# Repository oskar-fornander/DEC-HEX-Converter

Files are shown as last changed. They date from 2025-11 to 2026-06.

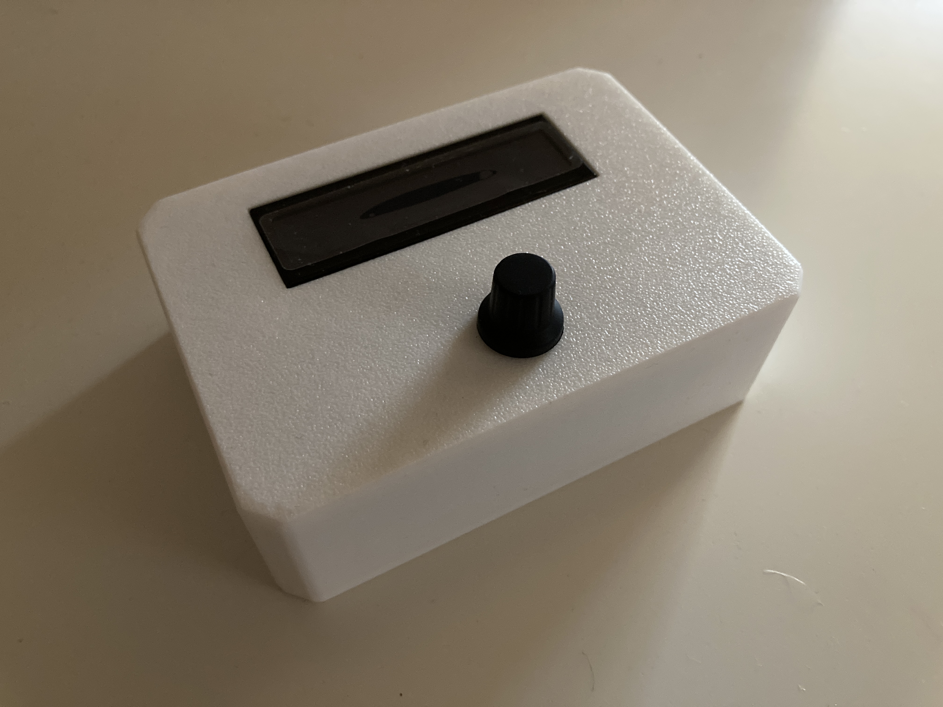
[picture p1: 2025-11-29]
model_b/images/DEC-HEX-Converter_B_01.jpg

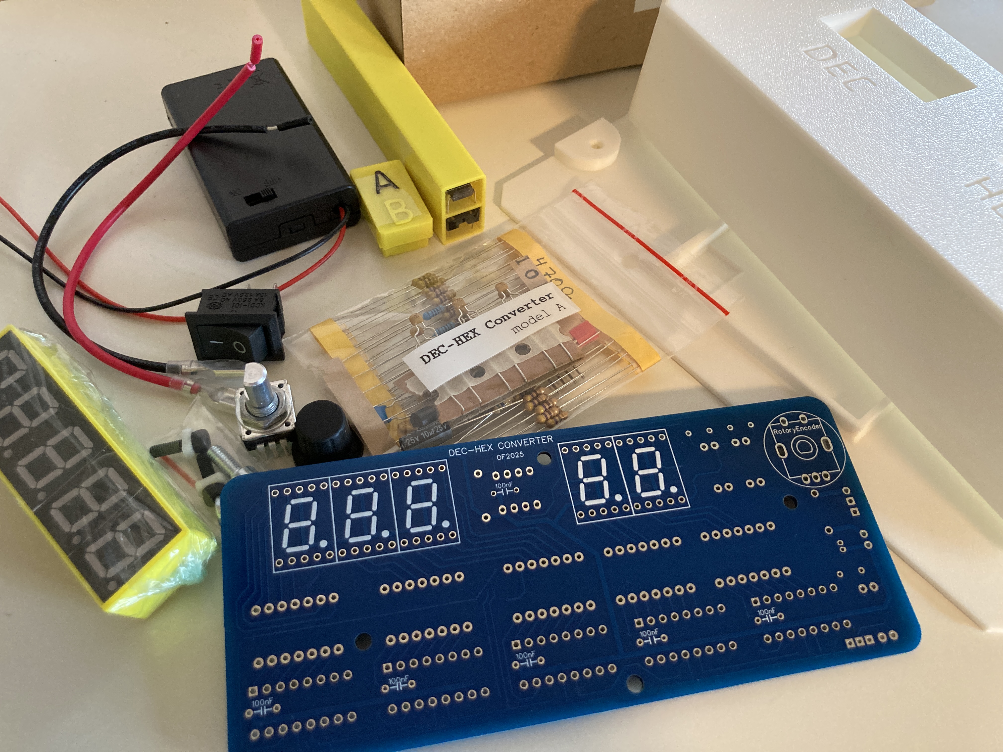
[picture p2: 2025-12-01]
model_a/images/DEC-HEX-Converter_A_05.JPG

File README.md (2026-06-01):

# DEC–HEX Converter: DIY Electronics Kit (Models A & B)

This repository contains the firmware, hardware design, and comprehensive documentation for the **DEC–HEX Converter**, a fun and functional DIY calculator kit. It is designed to help hobbyists practice their soldering skills while creating a useful, physical tool for converting between number systems.

**Quick Navigation:**
* [**Documentation in Swedish**](sv/README.md)
* **Ready to Buy?** See the [**Ordering Guide**](ordering.md)

## Key Features (Common to Both Models)

The DEC–HEX Converter is built around a simple, tactile interface:

* **Fast Conversion:** Quickly convert between Decimal and Hexadecimal number bases (and Binary depending on the model).
* **Rotary Encoder:** Use the responsive and precise rotary encoder to increment/decrement values. It provides satisfying tactile feedback with distinct steps for each change.
* **Intuitive Control:** **Rotate** to count up/down, and **Press** to reset the counter to zero.
* **The Brain:** Both units use the reliable **ATtiny85/45 microcontroller** for processing.
* **Enclosure:** The electronics are housed in a robust **3D-printed enclosure**.
* **The Kit:** Delivered as a complete kit with a **custom-designed PCB**, all necessary components, and a **pre-programmed microcontroller**—ideal for excellent **soldering practice**.
* **Customization:** The microcontroller is pre-programmed, but it can be **re-programmed**. The source code is available within this repository.

## Two Models

The DEC–HEX Converter comes in two variants, catering to different preferences for display type and soldering complexity:

### Model A: The Classic Display
* Displays values using bright, classic **seven-segment displays**.
* Converts between **Decimal** and **Hexadecimal**.
* Features a **dedicated power switch** and a power-saving sleep mode.
* *Involves more soldering.*

### Model B: The LCD Multi-Base Display
* Displays values on an **LCD (Liquid Crystal Display)**.
* Converts between **Decimal**, **Hexadecimal**, and **Binary**.
* **No power switch**; utilizes an ultra-low-power sleep mode and wakes up instantly when the knob is turned or pressed.
* *Involves less soldering.*

## Repository Contents

This repository is organized into specific directories for each model. All project files, documentation, and source code are provided below.

* **General Files:** Find pricing, licenses, and the Swedish documentation entry point.
* **Model-Specific:** Documentation, hardware files, and firmware are located within the dedicated `/model_a/` and `/model_b/` directories.

---

### Model A Files (`/model_a/`)

The following files are unique to the **seven-segment display** model:

| Document/File | Content Description | Path (Click to View) |
| :--- | :--- | :--- |
| **Firmware (.ino)** | The Arduino source code for the microcontroller. | [model\_a.ino](model_a/model_a.ino) |
| **Assembly Guide** | Step-by-step instructions for soldering and assembly. | [a\_assembly.md](model_a/docs/a_assembly.md) |
| **Specification** | Detailed feature list and technical specifications for Model A. | [a\_spec.md](model_a/docs/a_spec.md) |
| **Parts List** | Full Bill of Materials (BOM) listing all included components. | [a\_parts\_list.md](model_a/docs/a_parts_list.md) |
| **Schematics (PDF)** | Detailed hardware circuit diagram. | [a\_schematic.pdf](model_a/docs/a_schematic.pdf) |
| **Images** | Photos of the parts and the assembled unit. | [images/](model_a/images/) |
| **3D files** | Files for 3D-printing the enclosure. | [3d_model/](model_a/3d_model/) |

### Model B Files (`/model_b/`)

The following files are unique to the **LCD multi-base display** model:

| Document/File | Content Description | Path (Click to View) |
| :--- | :--- | :--- |
| **Firmware (.ino)** | The Arduino source code for the microcontroller. | [model\_b.ino](model_b/model_b.ino) |
| **Assembly Guide** | Step-by-step instructions for soldering and assembly. | [b\_assembly.md](model_b/docs/b_assembly.md) |
| **Specification** | Detailed feature list and technical specifications for Model B. | [b\_spec.md](model_b/docs/b_spec.md) |
| **Parts List** | Full Bill of Materials (BOM) listing all included components. | [b\_parts\_list.md](model_b/docs/b_parts_list.md) |
| **Schematics (PDF)** | Detailed hardware circuit diagram. | [b\_schematic.pdf](model_b/docs/b\_schematic.pdf) |
| **Images** | Photos of the parts and the assembled unit. | [images/](model_b/images/) |
| **3D files** | Files for 3D-printing the enclosure. | [3d_model/](model_b/3d_model/) |

### General Project Files

| File | Content Description | Path (Click to View) |
| :--- | :--- | :--- |
| **Order Guide** | Information on pricing and how to order your kit. | [ordering.md](ordering.md) |
| **Swedish Docs** | Entry point for all project documentation in Swedish. | [sv/](sv/README.md) |
| **License** | Software and hardware license information. | [LICENSE.md](LICENSE.md) |
---

**Interested in purchasing a kit?** Read more in the [**Ordering Guide**](ordering.md)!

---

> **A Note on Guarantees:** This is a hobby project. While I strive for high quality, I offer no formal guarantee. Please contact me directly if you encounter any issues with the unit or assembly process.

> **Sponsorship:** PCB prototypes for DEC-HEX-BIN Converter Model B were kindly sponsored by PCBWay.

/Oskar Fornander

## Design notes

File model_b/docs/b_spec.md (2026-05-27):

# DEC–HEX Converter, Model B

Electronics Kit

Looking for a sleek, physical device to quickly convert between decimal and hexadecimal values? This is the kit for you! You get the satisfaction of soldering and assembling it yourself, turning it into a rewarding and functional project.

* **Fast conversion** between decimal, hexadecimal, and binary numbers—in all directions.
* The **rotary encoder** provides responsive and precise tactile feedback, featuring distinct steps for each value increment/decrement.
* **Rotate** to count up/down, and **press** to reset the counter to zero.
* Values are displayed simultaneously in decimal, hexadecimal, and binary form using an **LCD (Liquid Crystal Display)**.
* **No power switch**; the unit automatically enters an **ultra-low-power sleep mode** after a period of inactivity. Wake the unit up by rotating the knob or pressing to reset.
* Powered by **4 AAA batteries**. Provides over **25 hours of active use**.
* The brain is an **ATtiny85/45 microcontroller**.
* Comes with a **3D-printed enclosure** (116mm x 82mm x 38mm).
* Delivered as a complete kit with carefully selected, high-quality components, a **pre-programmed microcontroller**, and a custom-designed **PCB**—making for simple assembly and excellent **soldering practice**. PCB prototypes for the current revision were kindly sponsored by PCBWay. Current kit use a slightly updated PCB revision with minor improvements compared to the version shown in some of the photos.
* The microcontroller (ATtiny85/45) is pre-programmed but can be **re-programmed**. The source code is available on GitHub.

*Read more in [**ordering.md**](../../ordering.md) for pricing and how to order your own kit.*

(Also check out Model A, which uses seven-segment displays instead of an LCD and involves slightly more soldering.)

/Oskar Fornander, 2025

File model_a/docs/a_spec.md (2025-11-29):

# DEC–HEX Converter, Model A

Electronics Kit

Looking for a sleek, physical device to quickly convert between decimal and hexadecimal values? This is the kit for you! You get the satisfaction of soldering and assembling it yourself, turning it into a rewarding and functional project.

* **Fast conversion** between decimal and hexadecimal numbers—in both directions.
* The **rotary encoder** provides responsive and precise tactile feedback, featuring distinct steps for each value increment/decrement.
* **Rotate** to count up/down, and **press** to reset the counter to zero.
* Values are displayed simultaneously in decimal and hexadecimal form using **seven-segment displays** (the color of the displays may vary from the images).
* Dedicated **power switch** for on/off control.
* Powered by **3 AAA batteries**. Provides over **10 hours of active use**.
* **Automatic sleep mode** after a few minutes of inactivity to save battery life. The display will blink intermittently to remind you to power the unit off.
* The brain is an **ATtiny85/45 microcontroller**, and shift registers are used to drive the displays.
* Comes with a **3D-printed enclosure** (172mm x 75mm x 38mm).
* Delivered as a complete kit with carefully selected, high-quality components, a **pre-programmed microcontroller**, and a custom-designed **PCB**—making for simple assembly and excellent **soldering practice**.
* The microcontroller (ATtiny85/45) is pre-programmed but can be **re-programmed**. The source code is available on GitHub.

*Read more in [**ordering.md**](../../ordering.md) for pricing and how to order your own kit.*

(Also check out Model B, which uses an LCD instead of seven-segment displays and shows binary values as well, but requires slightly less soldering.)

/Oskar Fornander, 2025

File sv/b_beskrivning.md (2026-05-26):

# DEC–HEX Converter, model B

Byggsats elektronik

Vill du ha ett smidigt sätt att konvertera mellan decimala och hexadecimala värden, och dessutom i form av en fysisk enhet, så ska du skaffa denna! Dessutom får du den som en byggsats med glädjen att löda ihop och montera den själv. 

- Snabb konvertering (åt alla håll) mellan decimala, hexadecimala och binära tal.
- Vredet ger taktil feedback och är responsiv och exakt, med fasta steg för varje värde. 
- Vrid för att räkna uppåt/nedåt och tryck för att nollställa räkneverket.
- Värden visas samtidigt i decimal, hexadecimal och binär form på en lcd.
- Ingen strömbrytare; enheten går själv i viloläge med mycket låg strömförbrukning efter en stunds inaktivitet. Väck enheten genom att virda på ratten eller trycka för att nollställa.
- Drivs av 4 AAA-batterier. Aktiv tid mer än 25 timmar.
- Hjärnan är en ATtiny85/45.
- 3D-printad inbyggnadslåda (116mm x 82mm x 38mm).
- Kommer som en byggsats med noggrant utvalda delar, förprogrammerad mikrokontroller och specialdesignad pcb – enkel montering och en god övning för att löda. PCB-prototyper för denna modell har sponsrats av PCBWay.
- Mikrokontrollern (ATtiny85/45) är förprogrammerad men kan också programmeras om.
- Levereras med alla komponenter välsorterade och packeterade i en kartong.

Kostnad: **599kr** Kan även köpas färdigmonterad (+500kr).

Frakt som spårbart paket med Postnord: 59kr

(Kolla även in modell A som istället för en LCD har sjusegmentdisplayer och erbjuder lite mer lödning.)

/Oskar Fornander, 2025

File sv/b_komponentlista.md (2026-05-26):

# Innehåll

Detta är innehållet i byggsatsen för **DEC-HEX Converter, model B**.

- [ ] 3D-printat hölje (1st)
- [ ] Specialdesignad PCB (1st) - PCB sponsrad av PCBWay
- [ ] Skruvar M3 (6st)
- [ ] Skruvar M4 (2st)
- [ ] 3D-printad distansbricka M3 2mm (2st)
- [ ] 3D-printad distansbricka M3 5mm (4st)
- [ ] Batterihållare (4 x AAA) (1st)
- [ ] DIL-hållare (DIP-8) (1st)
- [ ] ATtiny85/45, förprogrammerad (model B) (1st)
- [ ] LCD med I2C-kommunikation (1st)
- [ ] Anslutning för LCD, 4 stift (1st)
- [ ] Rotationsenkoder (1st)
- [ ] Ratt till rotationsenkoder (1st)
- [ ] Stiftlist (4 + 3 stift)
- [ ] NPN-transistor (PN2222A/2N2222A) (1st)
- [ ] LDO regulator MCP1702 (1st)
- [ ] Kondensator (elektrolyt) 47uF (1st)
- [ ] Kondensator (keramisk) 1uF (105 blå) (2st)
- [ ] Kondensator (keramisk) 100nF (1st)
- [ ] Kondensator (keramisk) 10nF (103 beige) (2st)
- [ ] Motstånd 1kΩ (1st) (brown-black-red)
- [ ] Motstånd 10kΩ (3st) (brown-black-orange)
- [ ] Motstånd 100kΩ (1st) (brown-black-yellow)

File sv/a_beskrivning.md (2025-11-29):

# DEC–HEX Converter, model A
Byggsats elektronik

Vill du ha ett smidigt sätt att konvertera mellan decimala och hexadecimala värden, och dessutom i form av en fysisk enhet, så ska du skaffa denna! Dessutom får du den som en byggsats med glädjen att löda ihop och montera den själv. 

- **Snabb konvertering** mellan decimala och hexadecimala tal – åt båda håll.
- **Rotationsenkodern** ger taktil feedback och är responsiv och exakt, med fasta steg för varje värde. 
- **Vrid** för att räkna uppåt/nedåt och **tryck** för att nollställa räkneverket.
- Värden visas samtidigt i decimal och hexadecimal form med **sjusegmentdisplayer** (färgen på displayerna kan vara en annan än på bilderna).
- **Strömbrytare** för att starta och stänga av.
- Drivs av **3 AAA-batterier**. Aktiv tid **mer än 10 timmar**.
- **Automatiskt viloläge** efter ett par minuters inaktivitet för att spara på batterierna: displayen blinkar i intervaller för att påminna dig om att stänga av den.
- Hjärnan är **mikrokontrollern ATtiny85/45** och skiftregister används för att skicka data till displayerna.
- Monteras i en **3D-printad inbyggnadslåda** (172mm x 75mm x 38mm).
- Kommer som en byggsats med noggrant utvalda delar, **förprogrammerad mikrokontroller** och **specialdesignad pcb** – enkel montering och en god övning för att löda.
- Mikrokontrollern (ATtiny85/45) är förprogrammerad men kan också **programmeras om**. Koden finns tillgänglig på GitHub.
- Levereras med alla komponenter välsorterade och packeterade i en kartong.

Kostnad: **599kr** Kan även köpas färdigmonterad (+500kr).

Frakt som spårbart paket med Postnord: 59kr

(Kolla även in modell B som istället för sjusegmentdisplayer har en LCD och även visar binära tal, men med lite mindre lödning.) 

/Oskar Fornander, 2025

(Detta är ett hobbyprojekt och jag lämnar ingen garanti, men ta kontakt om du får problem med enheten.)

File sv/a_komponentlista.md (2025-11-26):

# Innehåll

Detta är innehållet i byggsatsen för **DEC-HEX Converter, model A**.

- [ ] 3D-printat hölje (1st)
- [ ] Specialdesignad PCB (1st)
- [ ] Skruvar M3 (2st)
- [ ] Skruvar M4 (2st)
- [ ] 3D-printad distansbricka M3 2mm (2st)
- [ ] Batterihållare (3 x AAA) (1st)
- [ ] Strömbrytare med sladdar (1st)
- [ ] DIL-hållare DIP-16 (5st)
- [ ] Skiftregister (74HC595) (5st)
- [ ] DIL-hållare DIP-8 (1st)
- [ ] ATtiny85/45, förprogrammerad (model A) (1st)
- [ ] Sjusegmentdisplay (CA) (5st)
- [ ] Rotationsenkoder (1st)
- [ ] Ratt till rotationsenkoder (1st)
- [ ] Stiftlist (4 stift) (1st)
- [ ] Transistor (BC547B) (1st)
- [ ] Kondensator (elektrolyt) 10-47uF (1st)
- [ ] Kondensator (keramisk) 10uF (1st)
- [ ] Kondensator (keramisk) 100nF (6st)
- [ ] Kondensator (keramisk) 10nF (2st)
- [ ] Motstånd 470Ω (35st) (gul-lila-brun)
- [ ] Motstånd 10kΩ (6st) (brun-svart-orange)
- [ ] Motstånd 560kΩ (1st) (grön-blå-gul)
- [ ] Diod (1N5819) (1st)

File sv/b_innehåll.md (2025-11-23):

# Innehåll

Detta är innehållet i byggsatsen för **DEC-HEX Converter, model B**.

- [ ] 3D-printat hölje (1st)
- [ ] Specialdesignad PCB (1st)
- [ ] Skruvar M3 (6st)
- [ ] Skruvar M4 (2st)
- [ ] Bricka M3 2mm (2st)
- [ ] Bricka M3 5mm (4st)
- [ ] Batterihållare (4 x AAA) (1st)
- [ ] DIL-hållare (DIP-8) (1st)
- [ ] ATtiny85/45, förprogrammerad (model B) (1st)
- [ ] LCD med I2C-kommunikation (1st)
- [ ] Rotationsenkoder (1st)
- [ ] Ratt till rotationsenkoder (1st)
- [ ] Stiftlist (4 + 3 stift)
- [ ] NPN-transistor (PN2222A/2N2222A) (1st)
- [ ] LDO regulator MCP1702 (1st)
- [ ] Kondensator (elektrolyt) 47uF (1st)
- [ ] Kondensator (keramisk) 1uF (2st)
- [ ] Kondensator (keramisk) 100nF (1st)
- [ ] Kondensator (keramisk) 10nF (2st)
- [ ] Motstånd 1kΩ (1st) (brown-black-red)
- [ ] Motstånd 10kΩ (5st) (brown-black-orange)
- [ ] Motstånd 100kΩ (1st) (brown-black-yellow)

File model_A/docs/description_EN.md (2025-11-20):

# DEC–HEX Converter, Model A
Electronics Kit

Looking for a sleek, physical device to quickly convert between decimal and hexadecimal values? This is the kit for you! You get the satisfaction of soldering and assembling it yourself, turning it into a rewarding and functional project.

* **Fast conversion** between decimal and hexadecimal numbers—in both directions.
* The **rotary encoder** provides responsive and precise tactile feedback, featuring distinct steps for each value increment/decrement.
* **Rotate** to count up/down, and **press** to reset the counter to zero.
* Values are displayed simultaneously in decimal and hexadecimal form using **seven-segment displays** (the color of the displays may vary from the images).
* Dedicated power switch for **on/off** control.
* Powered by **3 AAA batteries**. Provides over **10 hours of active use**.
* **Automatic sleep mode** after a few minutes of inactivity to save battery life. The display will blink intermittently to remind you to power the unit off.
* The brain is an **ATtiny85/45 microcontroller**, and shift registers are used to drive the displays.
* Comes with a **3D-printed enclosure**.
* Delivered as a complete kit with carefully selected, high-quality components, a **pre-programmed microcontroller**, and a custom-designed **PCB**—making for simple assembly and excellent **soldering practice**.
* The microcontroller (ATtiny85/45) is pre-programmed but can be **re-programmed**. The source code is available on GitHub.
* All components are well-sorted and packaged in a box.

**Cost: 599 SEK** (Can also be purchased pre-assembled for +500 SEK).

Shipping as a trackable package with Postnord: 59 SEK

(Also check out Model B, which uses an LCD instead of seven-segment displays and shows binary values as well, but requires slightly less soldering.)

/Oskar Fornander, 2025

(This is a hobby project; I offer no guarantee, but please contact me if you encounter any problems with the unit.)

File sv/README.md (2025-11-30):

# DEC–HEX Converter: Elektronikbyggsats (Modell A & B)

Denna *repository* innehåller *firmware*, *hardware-design* och komplett dokumentation för **DEC–HEX Converter**, ett roligt och funktionellt byggsats-projekt. Den är utformad för att ge hobbyister chansen att öva sina lödkunskaper samtidigt som de skapar ett användbart, fysiskt verktyg för omvandling mellan talsystem.

**Snabblänkar:**
* [**Documentation in English**](../README.md)
* **Redo att köpa?** Se [**Beställningsguiden**](beställning.md)

## Huvudfunktioner (gemensamt för båda modellerna)

DEC–HEX Converter är byggd kring ett enkelt och taktilt gränssnitt:

* **Snabb konvertering:** Omvandla snabbt mellan *decimala* och *hexadecimala* talbaser (och *binära* beroende på modell).
* **Rotationsenkoder:** Använd den responsiva och exakta rotationsenkodern för att öka/minska värden. Den ger tydlig taktil *feedback* med distinkta steg för varje ändring.
* **Intuitiv styrning:** **Vrid** för att räkna uppåt/nedåt, och **tryck** för att nollställa räkneverket.
* **Hjärnan:** Båda enheterna använder den pålitliga **ATtiny85/45 mikrokontrollern** för bearbetning.
* **Kapsling:** Elektroniken är monterad i en robust **3D-printad inbyggnadslåda**.
* **Byggsatsen:** Levereras som ett komplett kit med ett **specialdesignat kretskort (PCB)**, alla nödvändiga komponenter och en **förprogrammerad mikrokontroller** – idealiskt för **lödövning**.
* **Anpassning:** Mikrokontrollern är förprogrammerad, men den kan **programmeras om**. Källkoden finns tillgänglig i denna *repository*.

## Två modeller

DEC–HEX Converter finns i två varianter, anpassade efter olika önskemål kring displaytyp och lödkomplexitet:

### Modell A: Sjusegmentdisplay
* Visar värden med ljusa, klassiska **sjusegmentdisplayer**.
* Konvertera mellan **decimal** och **hexadecimal**.
* Har en **dedikerad strömbrytare** och ett strömsparläge.
* *Innebär mer lödning*.

### Modell B: LCD-display
* Visar värden på en **LCD (Liquid Crystal Display)**.
* Konverterar mellan **decimal**, **hexadecimal** och **binär**.
* **Ingen strömbrytare**; använder ett *extremt strömsnålt* viloläge och vaknar omedelbart när vredet vrids eller trycks in.
* *Innebär mindre lödning*.

## Repositoryts innehåll

Denna *repository* är organiserad i specifika kataloger för varje modell. Alla projektfiler, dokumentation och källkod tillhandahålls nedan.

* **Allmänna Filer:** Här hittar du priser, licenser och ingången till den svenska dokumentationen.
* **Modellspecifikt:** Dokumentation, *hardware*-filer och *firmware* finns i de dedikerade katalogerna `/model_a/` och `/model_b/`.

---

### Modell A filer (`/model_a/`)

Följande filer är unika för modellen med **sjusegmentdisplay**:

| Dokument/fil | Beskrivning av innehåll | Sökväg (klicka för att se) |
| :--- | :--- | :--- |
| **Firmware (.ino)** | Arduino källkod för mikrokontrollern. | [model\_a.ino](../model_a/model_a.ino) |
| **Monteringsanvisning** | Steg-för-steg guide för lödning och slutmontering. | [a\_assembly.md](a_montering.md) |
| **Specifikation** | Detaljerad funktionslista och tekniska specifikationer för Modell A. | [a\_spec.md](a_beskrivning.md) |
| **Komponentlista (BOM)** | Fullständig lista över alla nödvändiga komponenter. | [a\_parts_list.md](a_komponentlista.md) |
| **Kretsschema (PDF)** | Detaljerat *hardware* kretsschema. | [a\_schematic.pdf](../model_a/docs/a_schematic.pdf) |
| **Bilder** | Foton på komponenter och den färdiga enheten. | [images/](../model_a/images/) |
| **3D filer** | Filer för 3D-printing av kapslingen. | [3d_model/](../model_a/3d_model/) |

### Modell B filer (`/model_b/`)

Följande filer är unika för modellen med **LCD-display**:

| Dokument/fil | Beskrivning av innehåll | Sökväg (klicka för att se) |
| :--- | :--- | :--- |
| **Firmware (.ino)** | Arduino källkod för mikrokontrollern. | [model\_b.ino](../model_b/model_b.ino) |
| **Monteringsanvisning** | Steg-för-steg guide för lödning och slutmontering. | [b\_assembly.md](b_montering.md) |
| **Specifikation** | Detaljerad funktionslista och tekniska specifikationer för Modell B. | [b\_spec.md](b_beskrivning.md) |
| **Komponentlista (BOM)** | Fullständig lista över alla nödvändiga komponenter. | [b\_parts_list.md](b_komponentlista.md) |
| **Kretsschema (PDF)** | Detaljerat *hardware* kretsschema. | [b\_schematic.pdf](../model_b/docs/b_schematic.pdf) |
| **Bilder** | Foton på komponenter och den färdiga enheten. | [images/](../model_b/images/) |
| **3D filer** | Filer för 3D-printing av kapslingen. | [3d_model/](../model_b/3d_model/) |

### Allmänna projektfiler (rotkatalog)

| Fil | Beskrivning av innehåll | Sökväg (klicka för att se) |
| :--- | :--- | :--- |
| **Beställningsguide** | Information om priser och hur du kan köpa din byggsats. | [beställning.md](beställning.md) |
| **English Documentation** | Projektdokumentation på engelska. | [README.md](../README.md) |
| **Licens** | Information om licens. | [LICENSE.md](../LICENSE.md) |

---

**Intresserad av att köpa en byggsats?** Läs mer i [**Beställningsguiden**](beställning.md)!

---

> **En anmärkning om garanti:** Detta är ett hobbyprojekt. Även om jag strävar efter hög kvalitet, lämnar jag ingen formell garanti. Vänligen kontakta mig direkt om du stöter på problem med enheten eller monteringsprocessen.

/Oskar Fornander

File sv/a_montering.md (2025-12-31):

# Monteringsguide: DEC–HEX Converter, modell A

Denna guide beskriver de enkla steg som krävs för att montera din byggsats av modell A. Tack vare det specialdesignade kretskortet (PCB) är komponenternas placering tydligt utmärkt, vilket gör detta till ett okomplicerat bygge och ett utmärkt projekt för lödövning.

**Beräknad tid:** 1–2 timmar (beroende på lödvana).

**Verktyg som krävs:** Lödkolv, lödtenn, sidavbitare (för att trimma ben), liten insexskruvmejsel, och hobbyklister (t.ex. limpistol eller superlim).

Det är avgörande att följa den rekommenderade lödordningen för att säkerställa enkel åtkomst till alla lödpunkter. Se [**Komponentlista**](a_komponentlista.md) (namn och antal) för att korrekt identifiera varje komponent. Alla genomhålskomponenter sticks in från komponentsidan (sidan med  markeringar) och löds på motsatt sida (lödsidan). Alla komponenters placering är tydligt markerade på komponentsidan.

### 1. Löda alla komponenter, börja med lågprofilkomponenter

Börja med att löda komponenterna platt mot kretskortet, lämpligen från de lägsta till de högsta.

* **Avkopplingskondensatorer (100nF, 6 st):** Dessa små keramiska kondensatorer ska lödas först. Detta är avgörande för att komma åt att löda dem då de delvis är placerade under IC-socklarna.
* **IC-socklar (fem DIP-16 och en DIP-8):** Löda socklarna för mikrokontrollern (ATtiny85/45) och skiftregistren (74HC595). Var uppmärksam på skåran (orienteringsmarkeringen) på sockeln; den måste matcha markeringen tryckt på kretskortet. Se till att avkopplingskondensatorerna är lödda före detta steg.
* **Motstånd:** Löda motstånden, följ markeringarna på kretskortet för deras värden (kontrollera komponentlistan för färgkoder om du är osäker). OBS: hoppa över de båda pull up-resistorerna för rotationsenkodern enligt bild och kopplingsdiagram.
* **Kondensatorer, diod och transistor:** Löda resten av de mindre komponenterna på plats enligt deras värden. Säkerställ att transistorn, dioden och elektrolytkondensatorn placeras med korrekt orientering/polaritet. Se kretskortets markeringar (t.ex. diodens rand, kondensatorns minusben).
* **Strömbrytare och batterilåda:** Löda kablarna för strömbrytaren och batterilådan, antingen direkt till kretskortet eller till stiftlister.
* **Sjusegmentsdisplayer:** Stick i och löda de fem 7-segmentsdisplayerna. Säkerställ att de är placerade platt mot kretskortet och i korrekt orientering.
* **Rotationsenkoder:** Placera och löda rotationsenkoderns fem stift samt dess fästflikar för att säkra den stadigt.

### 2. Sätt i mikrokontroller och integrerade kretsar

* Sätt försiktigt i den **förprogrammerade ATtiny85/45 mikrokontrollern** och alla **Skiftregister (74HC595)** i deras socklar. Skåran på IC-kretsens kropp måste matcha skåran på sockeln och trycket på kretskortet.

### 3. Förbered batterilådan

* Sätt i tre AAA-batterier.
* Säkerställ att batterilådans strömbrytare är satt till läge **PÅ**. Enheten kräver att denna brytare är permanent på, eftersom huvudströmbrytaren på kretskortet styr strömmen.
* Applicera hobbyklister (eller dubbelhäftande tejp) på den fasta botten av **batterilådan** (sidan motsatt det öppningsbara locket) och limma fast den säkert på det avsedda området på kapslingens **bottenplatta**.

### 4. Montera kretskortet

* Placera det färdigmonterade kretskortet i huvuddelen av den **3D-printade kapslingen**.
* Använd de medföljande **M3-skruvarna** och **distansbrickorna** för att fästa kretskortet säkert i hålen på kapslingen. Distansbrickorna säkerställer korrekt skruvdjup och ger ett säkert fäste för kretskortet. Skruva fast rotationsenkodern från framsidan och sätt på ratten.
* Montera **strömbrytaren** i sin öppning på kapslingen och anslut dess kablar till strömbrytaren.

### 5. Stäng kapslingen

* Placera bottenplattan (med den fastlimmade batterilådan) på huvudkapslingen.
* Säkra kapslingen med **M4-skruvarna** genom bottenplattan och in i huvudkapslingen.

**Grattis! Din DEC–HEX Converter, modell A, är nu färdigmonterad och redo att användas!**

---

/Oskar Fornander

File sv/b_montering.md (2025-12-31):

# Monteringsguide: DEC–HEX Converter, modell B

Denna guide beskriver de enkla steg som krävs för att montera din byggsats av modell B. Tack vare det specialdesignade kretskortet (PCB) är komponenternas placering tydligt utmärkt, vilket gör detta till ett okomplicerat bygge och ett utmärkt projekt för lödövning.

**Beräknad tid:** ca 1 timme (beroende på lödvana).

**Verktyg som krävs:** Lödkolv, lödtenn, sidavbitare (för att trimma ben), liten insexskruvmejsel, och hobbyklister (t.ex. limpistol eller superlim).

Se [**Komponentlista**](b_komponentlista.md) (namn och antal) för att korrekt identifiera varje komponent. Alla genomhålskomponenter sticks in från komponentsidan (sidan med  markeringar) och löds på motsatt sida (lödsidan). Alla komponenters placering är tydligt markerade på komponentsidan.

### 1. Löda alla komponenter, börja med lågprofilkomponenter

Börja med att löda komponenterna platt mot kretskortet, lämpligen från de lägsta till de högsta.

* **Motstånd:** Löda motstånden, följ markeringarna på kretskortet för deras värden (kontrollera komponentlistan för färgkoder om du är osäker). OBS: hoppa över de båda pull up-resistorerna för rotationsenkodern enligt bild och kopplingsdiagram.
* **Kondensatorer:** Löda de keramiska kondensatorerna enligt deras värden. Löda elektrolytkondensatorn och säkerställ att den placeras med korrekt orientering/polaritet enligt kretskortets markeringar. Denna kan vinklas ner mot kretskortet för att ta mindre plats på höjden.
* **Transistor och LDO-regulator**: Löda Transistor och LDO-regulatorn på respektive plats. Notera att de båda använder liknande kapslar; jämför beteckningarna på komponenterna för att skilja dem åt och säkerställ rätt orientering.
* **IC-sockel (DIP-8):** Löda sockeln för mikrokontrollern (ATtiny85/45). Var uppmärksam på orienteringsmarkeringen på sockeln; den måste matcha markeringen tryckt på kretskortet. 
* **Rotationsenkoder:** Placera och löda rotationsenkoderns fem stift samt dess fästflikar för att säkra den stadigt. Skruva fast den från framsidan och sätt på ratten.
* **Stiftlist och batterilåda:** Löda stiftlisten (4 stift) för anslutning av LCD:n. Löda batteriets kablar direkt eller på separat stiftlist. Notera anslutningens polaritet.

### 2. Sätt i mikrokontroller

* Sätt försiktigt i den **förprogrammerade ATtiny85/45 mikrokontrollern** i sin sockel. Skåran på IC-kretsens kropp måste matcha skåran på sockeln och trycket på kretskortet.

### 3. Förbered batterilådan

* Sätt i fyra AAA-batterier.
* Säkerställ att batterilådans strömbrytare är satt till läge **PÅ**. Enheten kräver att denna brytare är permanent på; när den är inaktiv går den in i viloläge som drar minimalt med ström.
* Applicera hobbyklister (eller dubbelhäftande tejp) på den fasta botten av **batterilådan** (sidan motsatt det öppningsbara locket) och limma fast den säkert på det avsedda området på kapslingens **bottenplatta**.

### 4. Montera kretskort och LCD

* Placera det färdigmonterade kretskortet i huvuddelen av den **3D-printade kapslingen**.
* Använd två av de medföljande **M3-skruvarna** och **distansbrickorna (2mm)** för att fästa kretskortet säkert i hålen på kapslingen. Distansbrickorna säkerställer korrekt skruvdjup och ger ett säkert fäste för kretskortet. Skruva fast rotationsenkodern från framsidan och sätt på ratten.
* Anslut medföljande **kablar (4 stift)** till LCD och PCB. **Viktigt:** Säkerställ korrekt anslutning genom att jämföra tryckt text vid stiften; stiften är i samma ordning på pcb:n även om beteckningarna kan vara olika (VSS = GND, VDD = VCC, SCK = SCL). Felaktig polaritet kan skada komponenter.
* Montera LCD:n med fyra av **M3-skruvarna** och **distansbrickorna (5mm)** Notera att kabeln måste anslutas till de fyra stiften innan LCD:n placeras på plats. För korrekt orientering ska texten på baksidan vara rätt orienterad.

### 5. Stäng kapslingen

* Placera bottenplattan (med den fastlimmade batterilådan) på huvudkapslingen.
* Säkra kapslingen med **M4-skruvarna** genom bottenplattan och in i huvudkapslingen.

**Grattis! Din DEC–HEX Converter, modell B, är nu färdigmonterad och redo att användas!**

---

/Oskar Fornander

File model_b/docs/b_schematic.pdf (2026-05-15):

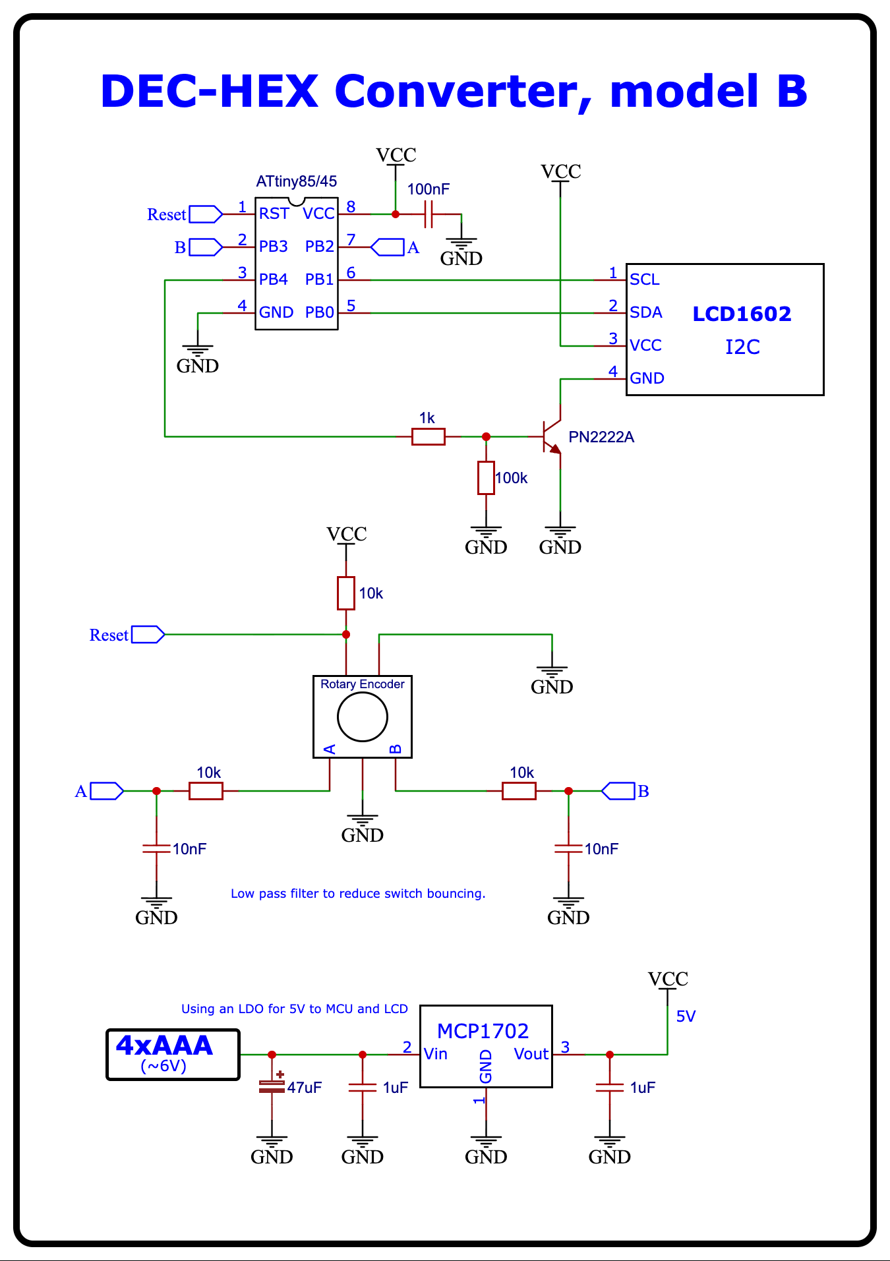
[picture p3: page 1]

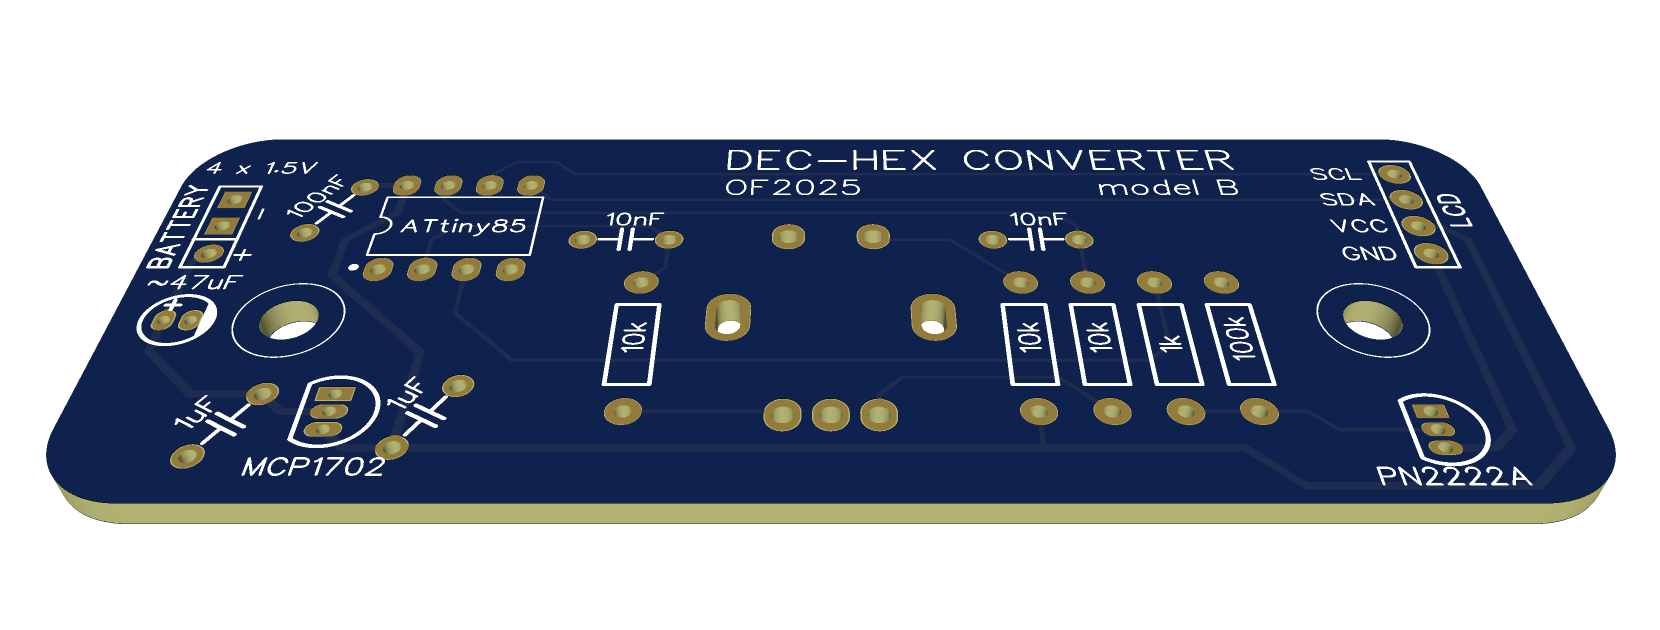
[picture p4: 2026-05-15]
model_b/images/b_pcb_front.png

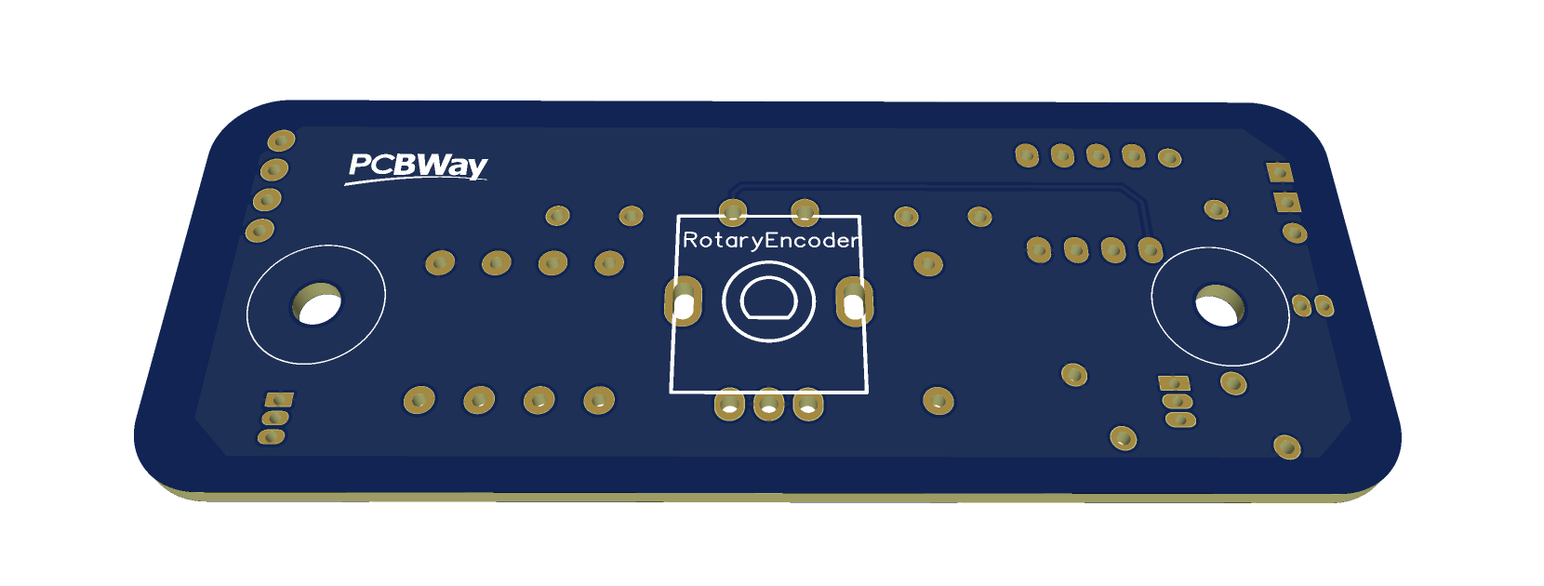
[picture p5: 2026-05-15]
model_b/images/b_pcb_back.png

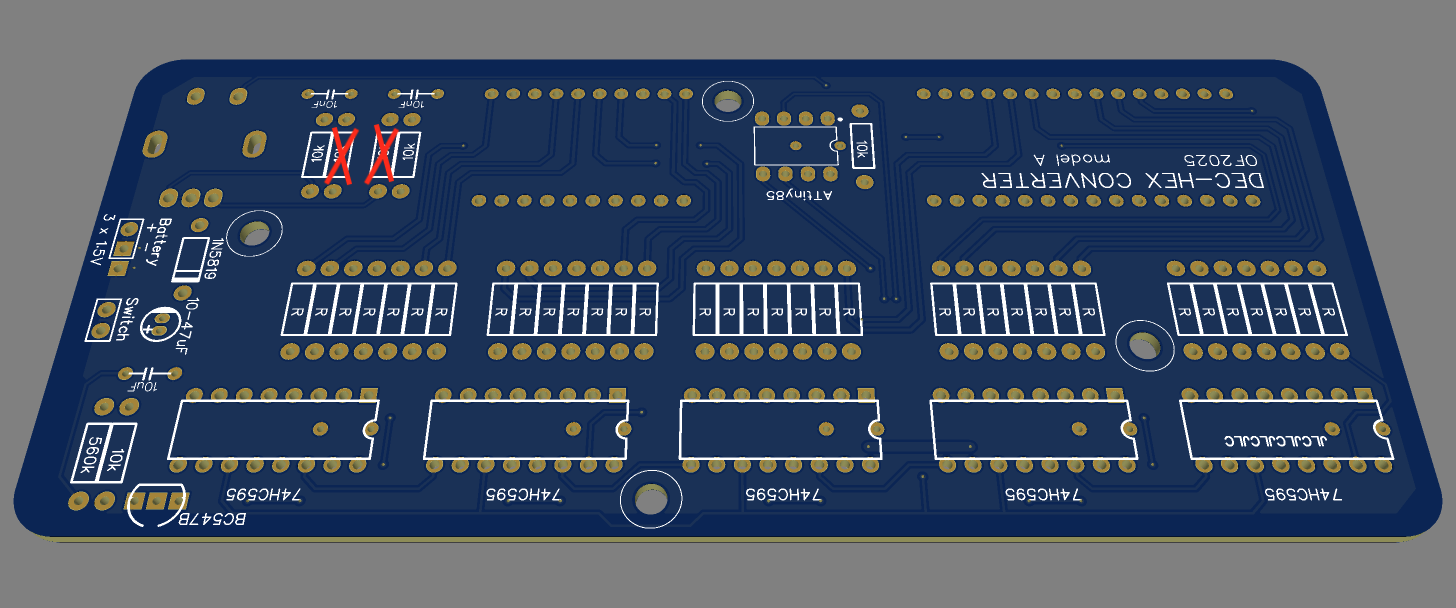
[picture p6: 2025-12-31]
model_a/images/a_pcb_back.png

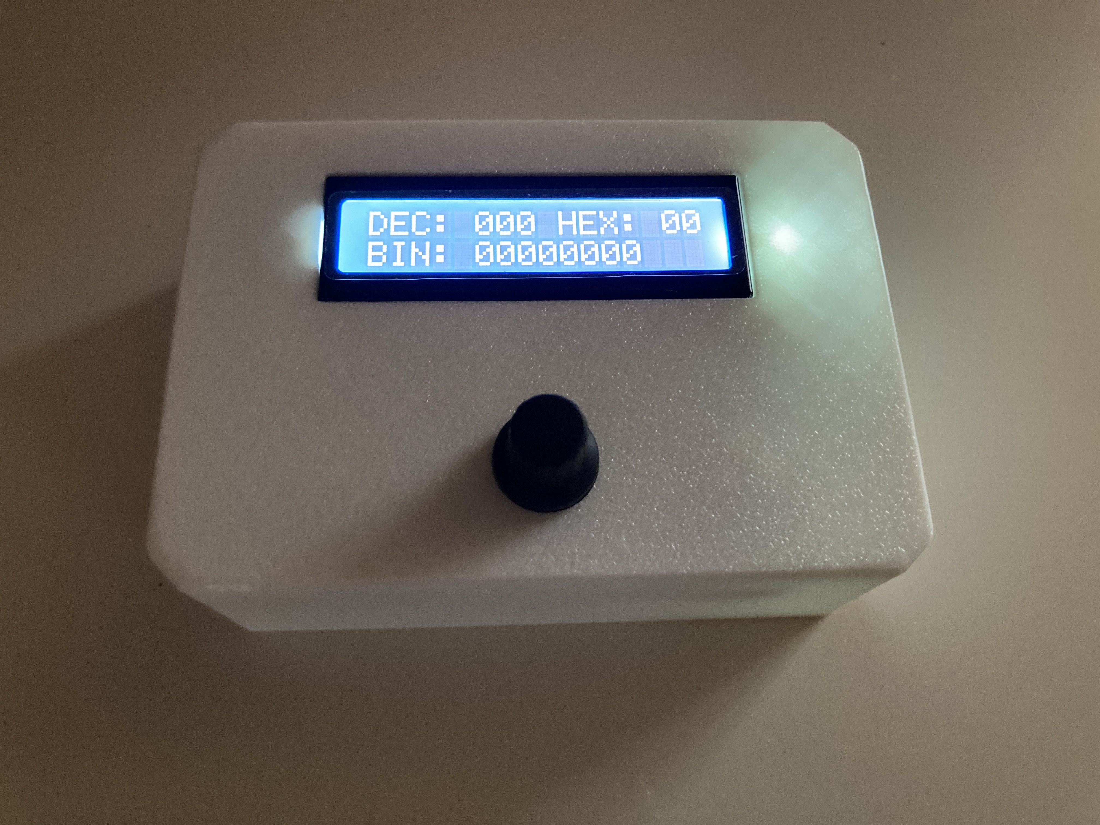
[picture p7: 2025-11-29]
model_b/images/DEC-HEX-Converter_B_02.jpg

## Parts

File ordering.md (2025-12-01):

# How to purchase your DEC–HEX Converter kit

Ready to start building? You can buy a complete kit for this rewarding electronics project today!

All components are **well-sorted** and packaged securely in a box. Comprehensive **documentation**, including assembly instructions and source code, is available here on GitHub. 

*Note: You can find detailed specifications for both Model A and Model B in the dedicated documentation pages on GitHub.*

## Pricing

* Model A: **599 SEK**
* Model B: **699 SEK**

Shipping cost will be added to the price. See below on how to order.

## How to Order

The DEC-HEX Converter kits are available to purchase on other sale platform. No links here, search for DEC-HEX Converter.

## Important Notes:

* This is a **hobby project**, and I offer no formal guarantee. However, please contact me immediately if you encounter any problems with the unit or the assembly process.
* **Good luck and much joy** with your new converter!
* **Contact & Support**: If you have questions about the products, code, or require assistance with assembly, please contact me directly at [OFDesignSWE@gmail.com](mailto:OFDesignSWE@gmail.com).

/Oskar Fornander

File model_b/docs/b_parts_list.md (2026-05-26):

# Content

This is the content of the kit for **DEC-HEX Converter, model B**.

- [ ] 3D printed enclosure (1pc)
- [ ] Custom designed PCB (1pc) - PCB sponsored by PCBWay
- [ ] Screw M3 (6pcs)
- [ ] Screw M4 (2pcs)
- [ ] 3D-printed spacer M3 2mm (2pcs)
- [ ] 3D-printed spacer M3 5mm (4pcs)
- [ ] Battery box (4 x AAA) (1pc)
- [ ] DIL socket (DIP-8) (1pc)
- [ ] ATtiny85/45, pre-programmed (model B) (1pc)
- [ ] LCD with I2C-communication (1pc)
- [ ] LCD Jumper Cable, 4-pin (1pc)
- [ ] Rotary encoder (1pc)
- [ ] Knob for rotary encoder (1pc)
- [ ] Pin header (7 pins) (1pc)
- [ ] NPN-transistor (PN2222A/2N2222A) (1pc)
- [ ] LDO regulator MCP1702 (1pc)
- [ ] Capacitor (electrolyte) 47uF (1pc)
- [ ] Capacitor (ceramic) 1uF (105 blue) (2pcs)
- [ ] Capacitor (ceramic) 100nF (1pc)
- [ ] Capacitor (ceramic) 10nF (103 beige) (2pcs)
- [ ] Resistor 1kΩ (1pc) (brown-black-red)
- [ ] Resistor 10kΩ (3pcs) (brown-black-orange)
- [ ] Resistor 100kΩ (1pc) (brown-black-yellow)

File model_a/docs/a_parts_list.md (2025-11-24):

# Content

This is the content of the kit for **DEC-HEX Converter, model A**. 

- [ ] 3D printed enclosure (1pc)
- [ ] Custom designed PCB (1pc)
- [ ] Screw M3 (2pcs)
- [ ] Screw M4 (2pcs)
- [ ] 3D-printed spacer M3 2mm (2pcs)
- [ ] Battery box (3 x AA) (1pc)
- [ ] Power switsh with wires (1pc)
- [ ] DIL socket DIP-16 (5pcs)
- [ ] Shift register (74HC595) (5pcs)
- [ ] DIL socket DIP-8 (1pc)
- [ ] ATtiny85/45, pre-programmed (model A) (1pc)
- [ ] Seven segment display (Common Anode) (5pcs)
- [ ] Rotary encoder (1pc)
- [ ] Knob for rotary encoder (1pc)
- [ ] Pin header (4 pins) (1pc)
- [ ] Transistor (BC547B) (1pc)
- [ ] Capacitor (electrolyte) 10-47uF (1pc)
- [ ] Capacitor (ceramic) 10uF (1pc)
- [ ] Capacitor (ceramic) 100nF (6pcs)
- [ ] Capacitor (ceramic) 10nF (2pcs)
- [ ] Resistor 470Ω (35pcs) (yellow-violet-brown)
- [ ] Resistor 10kΩ (6pcs) (brown-black-orange)
- [ ] Resistor 560kΩ (1pc) (green-blue-yellow)
- [ ] Diode (1N5819) (1pc)

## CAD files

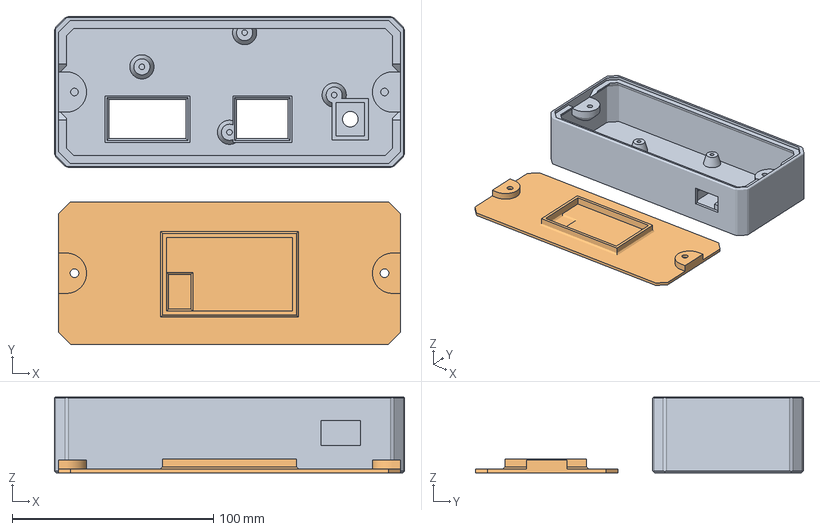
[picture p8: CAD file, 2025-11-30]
model_a/3d_model/DEC-HEX Converter model A box.3mf
174.0 x 162.9 x 37.6 mm
DEC-HEX Converter model A box.stl_1
DEC-HEX Converter model A box.stl_2

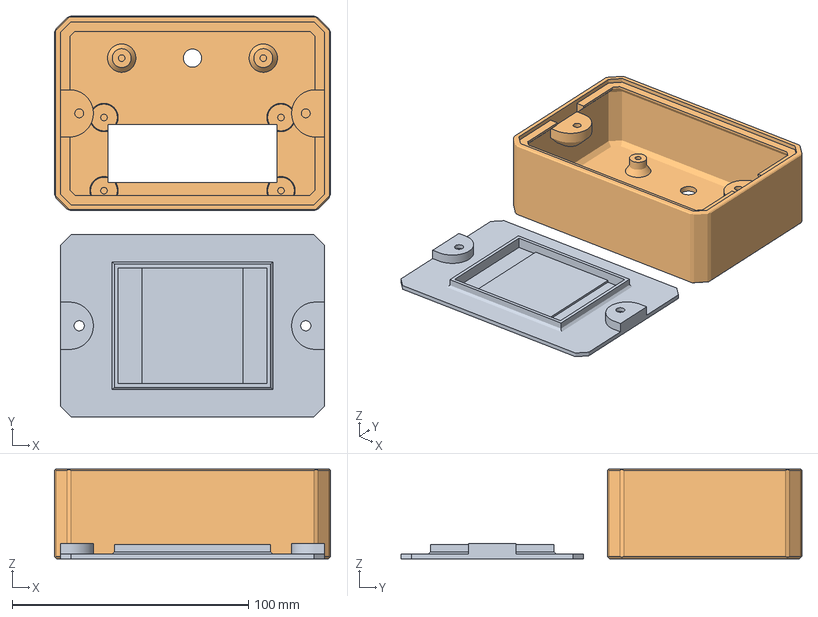
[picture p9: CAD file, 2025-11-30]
model_b/3d_model/DEC-HEX Converter model B box.3mf
117.0 x 169.9 x 38.0 mm
DEC-HEX Converter model B box.stl_1
DEC-HEX Converter model B box.stl_2

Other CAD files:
model_a/3d_model/DEC-HEX Converter model A box.stl
model_b/3d_model/DEC-HEX Converter model B box.stl

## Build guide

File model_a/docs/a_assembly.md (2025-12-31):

# Assembly Guide: DEC–HEX Converter, Model A

This guide provides the simple steps required to assemble your Model A kit. Thanks to the custom-designed PCB, the component layout is clearly marked, making this a straightforward build and an excellent soldering practice project.

**Estimated time:** 1–2 hours (depending on soldering experience).

**Tools required:** Soldering iron, solder, side cutters (for trimming leads), small hex screwdriver, and hobby glue (e.g., hot glue or super glue).

It is crucial to follow the recommended soldering order to ensure easy access to all pads. Refer to the [**Parts List**](a_parts_list.md) (name and number of pieces) to correctly identify each component. All through-hole components are inserted from the Component Side (the side with the silkscreen markings) and soldered on the reverse side (the Solder Side). All component locations are clearly marked on the Component Side silkscreen.

### 1. Solder all Components

Start by soldering components flush to the PCB, typically from shortest to tallest.

* **Decoupling Capacitors (100nF, 6pcs):** These small ceramic capacitors should be soldered first. This is critical for clearance, as they must fit beneath the subsequent IC sockets.
* **IC Sockets (five DIP-16 and one DIP-8):** Solder the sockets for the ATtiny85/45 and the shift registers 74HC595. Pay attention to the notch (orientation marker) on the socket; it must match the marker printed on the PCB. Ensure the decoupling capacitors are soldered before this step.
* **Resistors:** Solder the resistors, following the PCB markings for their values (check the Parts List for color codes if unsure). Note: skip the two pull up resistors for the rotary encoder, according to markings in the image and schematics.
* **Capacitors, diode and transistor:** Solder the rest of the smaller components in place according to their values. Ensure the transistor, diode, and electrolytic capacitor are placed with the correct orientation/polarity. Refer to the PCB markings (e.g., diode stripe, capacitor negative leg).
* **Power Switch and Battery Box:** Solder the wires of the dedicated ON/OFF switch and battery box, either directly to the pcb or on pin headers.
* **7-Segment Displays:** Insert and solder the five 7-segment displays. Ensure they are placed flat against the PCB and in the correct orientation.
* **Rotary Encoder:** Place and solder the five pins of the rotary encoder as well as the mounting tabs to secure it firmly.

### 2. Insert Microcontroller and Integrated Circuits

* Carefully insert the **pre-programmed ATtiny85/45 microcontroller** and the **74HC595 Shift Registers** into their sockets. The notch on the IC body must match the notch on the socket and the PCB silkscreen.

### 3. Prepare the Battery Box

* Install the three AAA batteries.
* Ensure the battery box's switch is set to the **ON** position. The unit requires this to be permanently ON since the main power switch on the PCB controls power.
* Apply hobby glue (or double-sided tape) to the fixed bottom of the **battery box** (the side opposite the opening lid) and glue it securely onto the designated area on the enclosure's **bottom plate**.

### 4. Mount the PCB

* Place the assembled PCB into the main part of the **3D-printed enclosure**.
* Use the provided **M3 screws** and **spacers** to fasten the PCB securely to the enclosure standoffs. The spacers ensure proper screw depth and provide a secure mounting for the PCB. Screw the rotary encoder on from the front and put the knob on.
* Mount the **Power Switch** in its opening on the enclosure and connect its wires to the switch.

### 5. Close the Enclosure

* Place the bottom plate (with the glued-on battery box) onto the main enclosure.
* Secure the enclosure using the **M4 screws** through the bottom plate and into the main housing.

**Congratulations! Your DEC–HEX Converter, model A, is now fully assembled and ready for use!**

---

/Oskar Fornander

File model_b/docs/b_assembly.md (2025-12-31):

# Assembly Guide: DEC–HEX Converter, Model B

This guide provides the simple steps required to assemble your Model B kit. Thanks to the custom-designed PCB (Printed Circuit Board), the component layout is clearly marked, making this a straightforward build and an excellent soldering practice project.

**Estimated time:** approx. 1 hour (depending on soldering experience).

**Tools required:** Soldering iron, solder, side cutters (for trimming leads), small hex screwdriver, and hobby glue (e.g., hot glue or super glue).

Refer to the [**Parts List**](b_parts_list.md) (name and number of pieces) to correctly identify each component. All through-hole components are inserted from the Component Side (the side with the silkscreen markings) and soldered on the reverse side (the Solder Side). All component locations are clearly marked on the Component Side.

### 1. Solder all Components

Start by soldering components flush to the PCB, typically from shortest to tallest.

* **Resistors:** Solder the resistors, following the PCB markings for their values (check the Parts List for color codes if unsure). Note: skip the two pull up resistors for the rotary encoder, according to markings in the image and schematics.
* **Capacitors:** Solder the ceramic capacitors according to their values. Solder the electrolytic capacitor and ensure it is placed with the correct orientation/polarity according to the PCB markings. This capacitor can be angled down toward the PCB to save vertical space.
* **Transistor and LDO Regulator:** Solder the Transistor and LDO regulator into their respective positions. Note that they both use similar packages; compare the markings on the components to differentiate them and ensure correct orientation.
* **IC Socket (DIP-8):** Solder the socket for the ATtiny85/45 microcontroller. Pay attention to the notch (orientation marker) on the socket; it must match the marker printed on the PCB.
* **Rotary Encoder:** Place and solder the five pins of the rotary encoder as well as the mounting tabs to secure it firmly.
* **Pin Header and Battery Box Wires:** Solder the pin header (4 pins) for the LCD connection. Then solder the battery box wires, either directly to the PCB or to a separate pin header. Note the connection polarity.

### 2. Insert Microcontroller

* Carefully insert the **pre-programmed ATtiny85/45 microcontroller** into its socket. The notch on the IC body must match the notch on the socket and the PCB silkscreen.

### 3. Prepare the Battery Box

* Install the four AAA batteries.
* Ensure the battery box's switch is set to the **ON** position. The unit requires this switch to be permanently ON; when inactive, the unit enters a minimal power consumption sleep mode.
* Apply hobby glue (or double-sided tape) to the fixed bottom of the **battery box** (the side opposite the opening lid) and securely glue it onto the designated area on the enclosure's **bottom plate**.

### 4. Mount the PCB and LCD

* Place the assembled PCB into the main part of the **3D-printed enclosure**.
* Use two of the provided **M3 screws** and **spacers (2mm)** to fasten the PCB securely into the enclosure holes. The spacers ensure proper screw depth and provide a secure mounting for the PCB. Screw the rotary encoder on from the front and put the knob on.
* Connect the included **4-pin cable** to the LCD and the PCB. **IMPORTANT:** Ensure the connection is correct by comparing the printed text near the pins. The pins are in the same order on the PCB, even though the labels may differ (VSS = GND, VDD = VCC, SCK = SCL). Incorrect polarity may damage the components.
* Mount the LCD using four of the **M3 screws** and **spacers (5mm)**. Note that the cables must be connected before the LCD is inserted and screwed in place. For correct orientation, the text on the backside should be oriented in the correct way.

### 5. Close the Enclosure

* Place the bottom plate (with the glued-on battery box) onto the main enclosure.
* Secure the enclosure using the **M4 screws** through the bottom plate and into the main housing.

**Congratulations! Your DEC–HEX Converter, Model B, is now fully assembled and ready for use!**

---

/Oskar Fornander

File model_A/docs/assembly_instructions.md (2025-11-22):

# Monteringsanvisningar

Monteringen av DEC-HEX Converter, model A, är tämligen enkel. Komponenterna lödas på kretskortet enligt beskrivningen på pcb:n. Ta hjälp av komponentlistan för att urskilja vilken som är vilken. Batteriboxen limmas fast på botten - observera att du först måste sätta den på on. Pcb:n skruvas fast i höljet, brickorna används för att skruvarna ska passa i längd.

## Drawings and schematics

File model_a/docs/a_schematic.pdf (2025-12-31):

## 3xAAA

# DEC-HEX Converter, model A

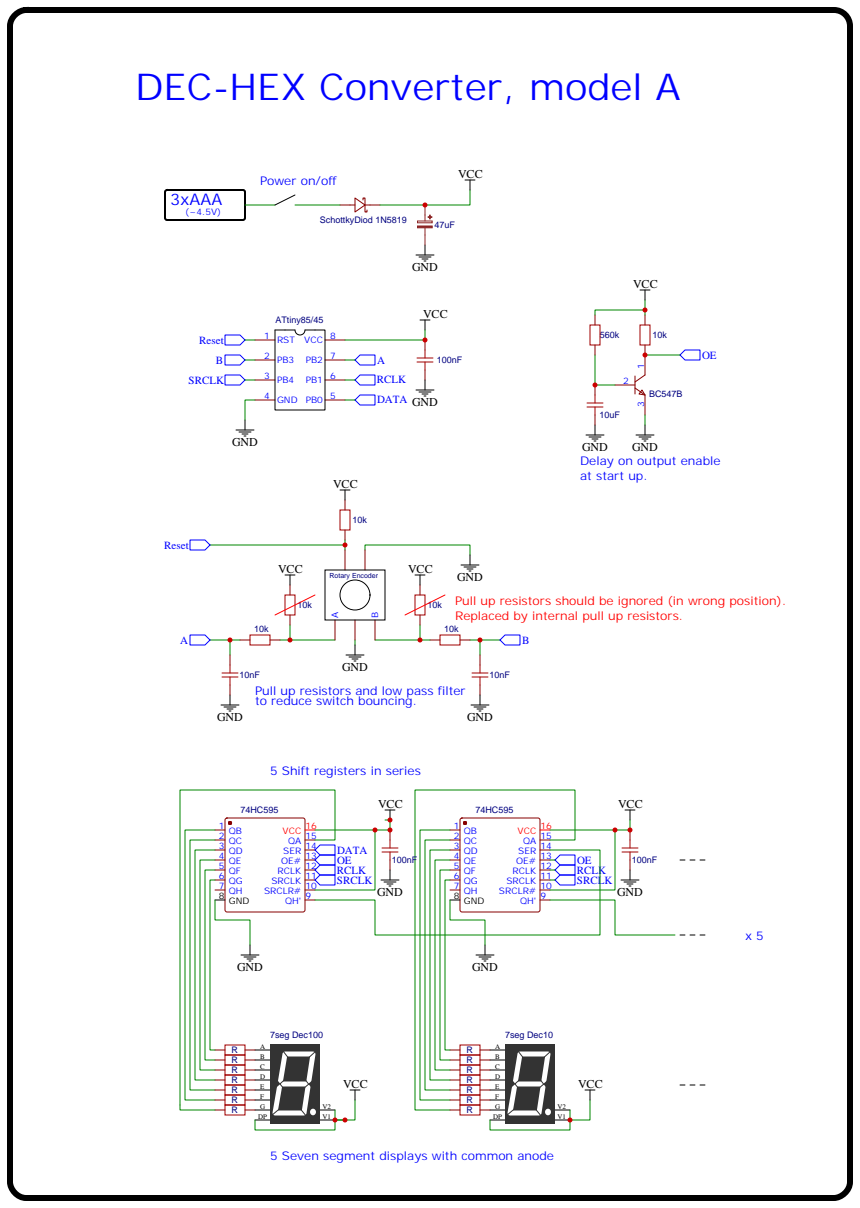
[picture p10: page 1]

Delay on output enable
at start up.

Pull up resistors should be ignored (in wrong position).
Replaced by internal pull up resistors.

Pull up resistors and low pass filter
to reduce switch bouncing.

5 Shift registers in series

SRCLR# 10 SRCLK 11 RCLK 12 OE# 13 SER 14 QA 15 VCC 16

5 Seven segment displays with common anode

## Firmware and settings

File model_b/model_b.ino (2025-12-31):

//
//    ┏━━━━━━━━━━━━━━━━━━━┱─────────┐
//    ┃ DEC-HEX Converter ┃ model B │
//    ┗━━━━━━━━━━━━━━━━━━━┹─────────┘
//             Oskar Fornander, 2025
//
//
//    DEC-HEX Converter, Oskar Fornander, July-October 2025
//    ATtiny85/45, seven segment displays or LCD and a rotary encoder, driven by 3 or 4 AAA-batteries.
//      Model A: Shift registers (74HC595) and seven segment displays, with power button.
//      Model B: LCD-display with I2C-module. No power button; enters sleep mode after being inactive a few moments.
//    This device will simultaneously count in decimal (0-255) and hexadecimal (00-FF) and in that way work as a converter between the two bases.
//    The code is optimized for speed, efficient use of memory and low power consumption on the ATtiny85 or ATtiny45, running at 8MHz.
//    
//    This file contains code for model B:
//      The device has no power button but is put to sleep after a time of inactivity. The last state of the counter is recovered when the device is woken with a turn on the rotary encoder knob (but reset when the knob is pushed).
//      Power consumption: ~25mA (active), <10uA (sleeping). With 4 AAA-batteries at 1000mAh the device can be active for about 36 hours and sleeping for a very long time.


/*
How does model B work?
  Start by rotating the knob (last displayed value is shown) or pressing it (the unit is reset).
  Rotate the knob to increase/decrease value shown as decimal and hexadecimal as well as binary.
  Press the knob to reset the counter to 0 (by restarting the ATtiny85 using RESET pin).
  Go to sleep after being inactive for some time (no power button).
  Power to LCD is controlled by mcu via a transistor.
  Let mcu wake up by interrupt from the rotary encoder.



Connections to the ATtiny85:

// Rotary Encoder: 3 pins (A, B + RESET)
// LCD (I2C): 3 pins (SDA, SCL, VCC), LCD 1602 with I2C connection: 2 lines of 16 characters

pin  Arduino pin type            connection
----|-----------|---------------|--------------
1    PB5/RESET                   Push button   | (Push button with external pull up resistor)
2    PB3         INPUT           B             | Rotary encoder, low pass filter and external pull up resistor for both A and B. 
3    PB4         OUTPUT          LCD power     | Power to LCD via transistor
4    -                           GND
5    PB0         OUTPUT          SDA           | Serial data for LCD (I2C)
6    PB1         OUTPUT          SCL           | Serial clock line for LCD (I2C)
7    PB2         INPUT,interrupt A             | (This pin can have external interrupt)
8    -                           VCC


Reset button will reset the ATtiny85, so the start up sequence must be short and reset the counter.

Text in LCD display (text to LCD is sent via I2C protocol) (2 x 16 characters):
   ┌────────────────┐    ┌────────────────┐
   │▉▉▉▉▉▉▉▉▉▉▉▉▉▉▉▉│    │DEC: 165 HEX: A5│
   │▉▉▉▉▉▉▉▉▉▉▉▉▉▉▉▉│    │BIN: 10100101   │
   └────────────────┘    └────────────────┘
*/

//#### Libraries #################################
#include <avr/pgmspace.h>
#include <avr/sleep.h>
#include <avr/power.h>
#include <avr/interrupt.h>
//#include <EEPROM.h>

//#### Defining pins #############################
//Define pins for rotary encoder
#define PIN_ROTARY_ENCODER_A PB2
#define PIN_ROTARY_ENCODER_B PB3

//Define pins for LCD
#define PIN_DISPLAY_DATA PB0
#define PIN_DISPLAY_CLOCK PB1
#define PIN_DISPLAY_VCC PB4

//#### Defining constants for LCD ################
//Pin mapping PCF8574 I2C module to LCD
#define RS 0  //Register select (COMMAND/DATA)
#define RW 1  //READ/WRITE
#define EN 2  //ENABLE (pulsed HIGH to LOW)
#define BL 3  //BACKLIGHT
#define D4 4  //Data bit 4
#define D5 5 
#define D6 6 
#define D7 7 
//LCD pin values
#define LCD_RS (1 << RS)
#define LCD_RW (1 << RW)
#define LCD_EN (1 << EN)
#define LCD_BL (1 << BL)
#define LCD_D4 (1 << D4)
#define LCD_D5 (1 << D5)
#define LCD_D6 (1 << D6)
#define LCD_D7 (1 << D7)

//Defining LCD constants used in the I2C communication with the LCD
//Commands and flags
#define LCD_ADDRESS 0x27 //LCD_ADDRESS is the I2C address to the LCD (defaults to 0x27))
#define READ 1 //READ/WRITE and COMMAND/DATA are sent to RW and RS respectively
#define WRITE 0
#define COMMAND 0
#define DATA 1
#define BACKLIGHT_ON LCD_BL
#define BACKLIGHT_OFF 0

//Clear display
#define LCD_CLEAR_DISPLAY 0x01
//Return home
#define LCD_RETURN_HOME 0x02
//Entry mode set
#define LCD_ENTRY_MODE_SET 0x04 //Example: LCD_ENTRY_MODE_SET | LCD_INCREMENT | LCD_DISPLAY_NO_SHIFT
#define LCD_INCREMENT 0x02
#define LCD_DECREMENT 0x00
#define LCD_DISPLAY_SHIFT 0x01
#define LCD_DISPLAY_NO_SHIFT 0x00
//Display on/off control
#define LCD_ON_OFF 0x08 //Example: LCD_ON_OFF | LCD_DISPLAY_ON | LCD_CURSOR_OFF | LCD_BLINKS_OFF
#define LCD_DISPLAY_ON 0x04
#define LCD_DISPLAY_OFF 0x00
#define LCD_CURSOR_ON 0x02
#define LCD_CURSOR_OFF 0x00
#define LCD_BLINKS_ON 0x01
#define LCD_BLINKS_OFF 0x00
//Cursor or display shift (used to correct or search the display)
#define LCD_CURSOR_OR_DISPLAY_SHIFT 0x10
#define LCD_SHIFT_CURSOR 0x00
#define LCD_SHIFT_DISPLAY 0x08
#define LCD_SHIFT_RIGHT 0x04
#define LCD_SHIFT_LEFT 0x00
//Function set
#define LCD_FUNCTION_SET_8BIT 0x30 //This is not used, only 4-bit mode
#define LCD_FUNCTION_SET_4BIT 0x20 //Example: LCD_FUNCTION_SET_4BIT | LCD_TWO_LINES | LCD_5X8_FONT 
#define LCD_ONE_LINE 0x00
#define LCD_TWO_LINES 0x08
#define LCD_5X8_FONT 0x00 //Only the 5x8 font can be used with display in 2 line mode
#define LCD_5X10_FONT 0x04
//Set Character Generator RAM Address
#define LCD_SET_CGRAM_ADDRESS 0x40 //0b01aaaaaa where aaaaaa is the address
//Set Display Data RAM Address
#define LCD_SET_DDRAM_ADDRESS 0x80 //0b1aaaaaaa where aaaaaa is the address. one line display: 0x00-0x4F, two line display: 0x00-0x27 for first line and 0x40-0x67 for second line.


//#### Constants and variables for sleep #########
#define WAIT_FOR_SLEEP 20000 //number of ms to wait from last action before going to sleep
#define WAKE_UP_DELAY 1000 //1 second
unsigned long lastTimeActive = 0; //Stores the time millis() after the last activity, to check for millis() - lastTimeActive > WAIT_FOR_SLEEP
unsigned long wakeUpTime = -WAKE_UP_DELAY; //millis() when woken up. Used to ignore rotation of the rotary encoder for a moment after wake up. Set to negative value to ignore this at startup and reset.

//#### Defining other variables ##################
byte counter = 0; //global counter variable in interval [0, 255], this is the value to be displayed in decimal and hexadecimal

//#### Defining variables for rotary encoder #####
//Bit fields to store the flags that keep track of the rotary encoder status
struct {
  uint8_t currentA : 1; //Previous and current readings of the rotary encoder pins A and B. 1 for true and 0 for false. Using single bit sto store information for each.
  uint8_t prevA : 1;
  uint8_t currentB : 1;
  uint8_t prevB : 1;
  uint8_t transition : 4; //Transitions from one state to another (4 bits: A'B'AB)
  int8_t counter : 4; //Counting states of the rotary encoder. 4 bits to store values from -4 to 4 (-8 to 7)
  uint8_t valueChanged : 1; //Flag to indicate that the value of counter has changed (using one bit instead of one byte with a comparison number to save space)
} rotaryStates;

//#### Defining look up tables ###################
//Look up tables for decimal digits, used to speed up the calculations (from ~80 cycles (80us) to ~3 cycles(375ns)). These tables takes 3 * 256 bytes of memory. Stored in Progmem to save space in the dynamic memory for global variables. This way the program can fit on an ATtiny45 as well.
const uint8_t dec1_table[256] PROGMEM = {0, 1, 2, 3, 4, 5, 6, 7, 8, 9, 0, 1, 2, 3, 4, 5, 6, 7, 8, 9, 0, 1, 2, 3, 4, 5, 6, 7, 8, 9, 0, 1, 2, 3, 4, 5, 6, 7, 8, 9, 0, 1, 2, 3, 4, 5, 6, 7, 8, 9, 0, 1, 2, 3, 4, 5, 6, 7, 8, 9, 0, 1, 2, 3, 4, 5, 6, 7, 8, 9, 0, 1, 2, 3, 4, 5, 6, 7, 8, 9, 0, 1, 2, 3, 4, 5, 6, 7, 8, 9, 0, 1, 2, 3, 4, 5, 6, 7, 8, 9, 0, 1, 2, 3, 4, 5, 6, 7, 8, 9, 0, 1, 2, 3, 4, 5, 6, 7, 8, 9, 0, 1, 2, 3, 4, 5, 6, 7, 8, 9, 0, 1, 2, 3, 4, 5, 6, 7, 8, 9, 0, 1, 2, 3, 4, 5, 6, 7, 8, 9, 0, 1, 2, 3, 4, 5, 6, 7, 8, 9, 0, 1, 2, 3, 4, 5, 6, 7, 8, 9, 0, 1, 2, 3, 4, 5, 6, 7, 8, 9, 0, 1, 2, 3, 4, 5, 6, 7, 8, 9, 0, 1, 2, 3, 4, 5, 6, 7, 8, 9, 0, 1, 2, 3, 4, 5, 6, 7, 8, 9, 0, 1, 2, 3, 4, 5, 6, 7, 8, 9, 0, 1, 2, 3, 4, 5, 6, 7, 8, 9, 0, 1, 2, 3, 4, 5, 6, 7, 8, 9, 0, 1, 2, 3, 4, 5, 6, 7, 8, 9, 0, 1, 2, 3, 4, 5};
const uint8_t dec2_table[256] PROGMEM = {0, 0, 0, 0, 0, 0, 0, 0, 0, 0, 1, 1, 1, 1, 1, 1, 1, 1, 1, 1, 2, 2, 2, 2, 2, 2, 2, 2, 2, 2, 3, 3, 3, 3, 3, 3, 3, 3, 3, 3, 4, 4, 4, 4, 4, 4, 4, 4, 4, 4, 5, 5, 5, 5, 5, 5, 5, 5, 5, 5, 6, 6, 6, 6, 6, 6, 6, 6, 6, 6, 7, 7, 7, 7, 7, 7, 7, 7, 7, 7, 8, 8, 8, 8, 8, 8, 8, 8, 8, 8, 9, 9, 9, 9, 9, 9, 9, 9, 9, 9, 0, 0, 0, 0, 0, 0, 0, 0, 0, 0, 1, 1, 1, 1, 1, 1, 1, 1, 1, 1, 2, 2, 2, 2, 2, 2, 2, 2, 2, 2, 3, 3, 3, 3, 3, 3, 3, 3, 3, 3, 4, 4, 4, 4, 4, 4, 4, 4, 4, 4, 5, 5, 5, 5, 5, 5, 5, 5, 5, 5, 6, 6, 6, 6, 6, 6, 6, 6, 6, 6, 7, 7, 7, 7, 7, 7, 7, 7, 7, 7, 8, 8, 8, 8, 8, 8, 8, 8, 8, 8, 9, 9, 9, 9, 9, 9, 9, 9, 9, 9, 0, 0, 0, 0, 0, 0, 0, 0, 0, 0, 1, 1, 1, 1, 1, 1, 1, 1, 1, 1, 2, 2, 2, 2, 2, 2, 2, 2, 2, 2, 3, 3, 3, 3, 3, 3, 3, 3, 3, 3, 4, 4, 4, 4, 4, 4, 4, 4, 4, 4, 5, 5, 5, 5, 5, 5};
const uint8_t dec3_table[256] PROGMEM = {0, 0, 0, 0, 0, 0, 0, 0, 0, 0, 0, 0, 0, 0, 0, 0, 0, 0, 0, 0, 0, 0, 0, 0, 0, 0, 0, 0, 0, 0, 0, 0, 0, 0, 0, 0, 0, 0, 0, 0, 0, 0, 0, 0, 0, 0, 0, 0, 0, 0, 0, 0, 0, 0, 0, 0, 0, 0, 0, 0, 0, 0, 0, 0, 0, 0, 0, 0, 0, 0, 0, 0, 0, 0, 0, 0, 0, 0, 0, 0, 0, 0, 0, 0, 0, 0, 0, 0, 0, 0, 0, 0, 0, 0, 0, 0, 0, 0, 0, 0, 1, 1, 1, 1, 1, 1, 1, 1, 1, 1, 1, 1, 1, 1, 1, 1, 1, 1, 1, 1, 1, 1, 1, 1, 1, 1, 1, 1, 1, 1, 1, 1, 1, 1, 1, 1, 1, 1, 1, 1, 1, 1, 1, 1, 1, 1, 1, 1, 1, 1, 1, 1, 1, 1, 1, 1, 1, 1, 1, 1, 1, 1, 1, 1, 1, 1, 1, 1, 1, 1, 1, 1, 1, 1, 1, 1, 1, 1, 1, 1, 1, 1, 1, 1, 1, 1, 1, 1, 1, 1, 1, 1, 1, 1, 1, 1, 1, 1, 1, 1, 2, 2, 2, 2, 2, 2, 2, 2, 2, 2, 2, 2, 2, 2, 2, 2, 2, 2, 2, 2, 2, 2, 2, 2, 2, 2, 2, 2, 2, 2, 2, 2, 2, 2, 2, 2, 2, 2, 2, 2, 2, 2, 2, 2, 2, 2, 2, 2, 2, 2, 2, 2, 2, 2, 2, 2};


void setup() {
  //Pins for display (using I2C)
  //DDRB -> set direction (0 = input, 1 = output)
  PORTB &= ~(1 << PIN_DISPLAY_CLOCK); //I2C SCL for LCD (constant value: LOW; only the DDRB is changed between input and output: output LOW or input without internal pull up resistor)
  PORTB &= ~(1 << PIN_DISPLAY_DATA); //I2C SDA for LCD (constant value: LOW)
  PORTB &= ~(1 << PIN_DISPLAY_VCC); //Pin controling power to the LCD via NPN transistor (PN2222A). OFF: input, with no pullup (high impedance). ON: output HIGH
  DDRB &= ~(1 << PIN_DISPLAY_VCC); 

  DDRB &= ~(1 << PIN_DISPLAY_CLOCK); //Set I2C SCL and SDA as input (0) (without pullup), i.e. HIGH with external pull up resistor
  DDRB &= ~(1 << PIN_DISPLAY_DATA);

  //Pins for Rotary encoder (push button is connected to reset pin)
  pinMode(PIN_ROTARY_ENCODER_A, INPUT_PULLUP); //Internal pullup resistors
  pinMode(PIN_ROTARY_ENCODER_B, INPUT_PULLUP);
  //Using polling instead of interrupt for changing the counter with the rotary encoder. But interrupts are used to wake the mcu up from sleep.

  sei(); //Set global interrupts

  //Set starting values for these flags
  rotaryStates.currentA = 1;
  rotaryStates.currentB = 1;
  rotaryStates.prevA = 1;
  rotaryStates.prevB = 1;
  rotaryStates.counter = 0;
  rotaryStates.valueChanged = 0;

  bool error = true;
  int tries = 3;
  while (error && tries--) {
    error = !displayInitialize(); //Initialize and clear the display as soon as possible after startup, since the RESET button is used to reset the counter (by restarting the ATtiny85). 
    delay(100);
  }
  if (error) { //Failing to initialize the display
    goToSleep();
  }
  //displayFill(0xff);
  //displayClear(); //Not needed; after displayInitialize() the LCD is cleared

  showValue(counter, true); //Show the counter value on the display (after reset it will be 0), true makes sure to also write the extra data and not only the numbers themselves.
}

ISR(PCINT0_vect) {
  //This ISR is called when PB2 (PCINT2) gives an interrupt.
  //Used only to wake up from sleep. No need to do anything here ...
}

void loop() {
  //Use polling instead of interrupt for reading the quadrature signal of the rotary encoder.
  //
  //  A----|    |------
  //       |----|
  //  
  //  B------|    |------
  //         |----|
  //  
  //  AB 11 01 00 10 11
  //    CW-->   <-- CCW
  
  if (millis() - wakeUpTime < WAKE_UP_DELAY) return; //Do nothing for a moment after wake up

  //Polling the status of the rotary encoder to detect rotations
  rotaryStates.currentA = !!(PINB & (1 << PIN_ROTARY_ENCODER_A)); //Read pins, faster than digitalRead()
  rotaryStates.currentB = (PINB >> PIN_ROTARY_ENCODER_B) & 1; //An equivalent way of reading the value. Both gives 1 or 0 as the result.
  rotaryStates.transition = (rotaryStates.prevA << 3) | (rotaryStates.prevB << 2) | (rotaryStates.currentA << 1) | rotaryStates.currentB; //A'B'AB

  switch (rotaryStates.transition) { //All valid transitions (gray code) are listed as cases here
    case 0b1101: //Valid transitions for clockwise rotation
    case 0b0100: //01 -> 00
    case 0b0010:
    case 0b1011:
      rotaryStates.counter++; //increasing the small counter with one for each valid transition.
      rotaryStates.prevA = rotaryStates.currentA;
      rotaryStates.prevB = rotaryStates.currentB;
      break;
    case 0b1110: //Valid transitions for counter clockwise rotation
    case 0b1000:
    case 0b0001:
    case 0b0111:
      rotaryStates.counter--; //decreasing small counter
      rotaryStates.prevA = rotaryStates.currentA;
      rotaryStates.prevB = rotaryStates.currentB;
      break;
    default:
      //No valid transition
      break;
  }
  if (rotaryStates.counter >= 4) { //Clock wise: advance counter when 4 states are registered (that is one tick on the rotary encoder)
    rotaryStates.counter = 0; //Reset the small counter
    counter++; //Increase the global counter
    rotaryStates.valueChanged = 1; //Indicate that the value of counter has changed
  } else if (rotaryStates.counter <= -4) { //Counter clock wise
    rotaryStates.counter = 0;
    counter--; //Decrease the global counter
    rotaryStates.valueChanged = 1; 
  }

  //Update display if value of the counter is changed
  if (rotaryStates.valueChanged) {
    showValue(counter, false); //Update value (only the numbers) (~175us?)
    rotaryStates.valueChanged = 0; //Clear flag
    lastTimeActive = millis(); //Update the last time of activity on the device, i.e. reset the sleep timer
  }

  if (millis() - lastTimeActive > WAIT_FOR_SLEEP) {
    goToSleep(); //Time to shut down after a long time of inactivity
  }
}

void goToSleep() {
  //This is used as an automatic power saving feature, after the unit has been left turned on for some time. Turn off the LCD and let the ATtiny85 go into deep sleep to save power, from a few mA down to below 1uA
  //displayClear(); //Display clear - no need for this
  displayOff(); //Display off
  ADCSRA &= ~(1 << ADEN); //Turn off ADC
  power_adc_disable();
  power_timer0_disable();
  power_timer1_disable();
  power_usi_disable();
  // Leave PCINT on to enable interrupt for wake up without restarting the code (running setup())
  GIFR |= (1 << PCIF); //Clear Pin change interrupt flag  
  GIMSK |= (1 << PCIE); //Enable pin change interrupts
  PCMSK |= (1 << PCINT2); //Enable interrupt on PB2 (ISR declared above)
  set_sleep_mode(SLEEP_MODE_PWR_DOWN);
  sleep_bod_disable(); //Turn off BOD
  sleep_enable();
  sleep_cpu(); //Activate sleeping mode

  // --- MCU is sleeping --- //

  sleep_disable(); //mcu just woke up
  GIMSK &= ~(1 << PCIE); //Disable pin change interrupts
  power_all_enable();
  wakeUpTime = millis();
  lastTimeActive = millis();
  displayInitialize(); //Restart the display at wake up
  showValue(counter, true); //Show the current value on the display again after wake up, the value is still in the variable counter when woken by a turn of the knob, if reset by press it is cleared and the unit restarts from scratch. true to not just update the values but also write the text.
}

//####################################

void shortDelay() {
  //no-operation gives 125ns of delay at 8MHz, instead of delayMicroseconds(1), about up to 100ns is needed.
  //delayMicroseconds(1);
  __asm__("nop\n\t"); //nop -- this is removed by the compiler ... Use _delay_ms() and delayMicroseconds() instead, none of which is dependent on global interrupts.
}

void dataHigh() {
  //Set data bit (I2C SDA) for display to 1 (send a 1)
  DDRB &= ~(1 << PIN_DISPLAY_DATA); //Set SDA as input without pullup - external pullup resistors pulls the serial data line HIGH
}
void dataLow() {
  //Clear data bit (I2C SDA) for display to 0 (send a 0)
  DDRB |= (1 << PIN_DISPLAY_DATA); //Set SDA as output
}

void clockHigh() {
  //Set clock (I2C SCL) HIGH
  DDRB &= ~(1 << PIN_DISPLAY_CLOCK); //SCL as input without pullup -> HIGH
}
void clockLow() {
  //Set clock (I2C SCL) LOW
  DDRB |= (1 << PIN_DISPLAY_CLOCK); //SCL as output low -> LOW
}
void pulseClock() {
  //Pulse I2C SCL high with SDA stable
  clockHigh();
  delayMicroseconds(5); //Delay (>4us)
  clockLow();
}

bool I2CStart(byte mode) {
  //Send start condition before transmitting data, followed by address and read/write bit
  //mode is either READ (1) or WRITE (0). Address is sent together with read/write so data can be transmited after this.
  //Both data and clock lines remain HIGH when the bus is not busy. A HIGH-to-LOW transition of the data line, while the clock is HIGH is defined as the start condition. 
  dataHigh(); //Make sure SCL remains HIGH and SDA is HIGH from start
  clockHigh();
  delayMicroseconds(5); //Bus free time and start condition set-up time is >4.7us
  dataLow(); //Set SDA LOW 
  delayMicroseconds(5); //Start condition hold time is >4us
  clockLow(); //Set SCL LOW
  //Send address and mode (READ/WRITE)
  int tries = 3; //Make a few tries before quitting
  while (!sendByte((LCD_ADDRESS << 1) | mode)) { //Address is 7 bits and are combined with the read/write bit. ACK is true if ok and ACK is false if not received properly.
    if (!tries--) { 
      I2CStop();
      return false;
    }
  }
  return true;
}
void I2CStop() {
  //Send stop condition after transmitting data
  //A LOW-to-HIGH transition of the data line while the clock is HIGH is defined as the stop condition. 
  dataLow(); //Make sure SDA is LOW from start
  clockHigh(); //Set SCL HIGH
  delayMicroseconds(5); //Stop condition set-up time is >4us
  dataHigh(); //Set SDA HIGH 
}
bool ack() {
  //Read Acknowledge bit
  dataHigh(); //Let go of the SDA line
  delayMicroseconds(5);
  clockHigh();
  delayMicroseconds(5);
  bool ACK = (PINB & (1 << PIN_DISPLAY_DATA)); //read SDA, 0 is ACK 1 is NACK
  clockLow();                                                 
  return !ACK; //Return true for ACK and false for NACK (the negation makes sure the value is either true (1) or false (0) no matter the pin in PORTB)
}

bool sendByte(byte value) {
  //Send one byte of data to LCD with I2C protocoll via PCF8574
  //One data bit is transferred during each clock pulse. The data on the SDA line must remain stable during the HIGH period of the clock pulse
  //The number of data bytes transferred between the start and the stop conditions from transmitter to receiver is not limited. Each byte of eight bits is followed by one acknowledge bit. The acknowledge bit is a HIGH level put on the bus by the transmitter whereas the master generates an extra acknowledge related clock pulse.
  for (int i = 0; i < 8; i++) {
    if ((value & 0x80) == 0) { //Send MSB first
      dataLow(); 
    } else {
      dataHigh();
    }
    delayMicroseconds(5); //>4.7us
    pulseClock();
    value = value << 1;
  } 
  //Acknowledge bit
  if (ack()) { //Acknowledged
    return true;
  } else { //Not acknowledged
    return false; //Let the calling function decide what to do with ACK or NACK.
  }
}

byte buildByte(byte nibble, byte mode) {
  //Build the data to send with I2C based on values for D4-D7 etc.
  byte value = 0; 
  value |= (nibble & 0x1)? LCD_D4 : 0;
  value |= (nibble & 0x2)? LCD_D5 : 0;
  value |= (nibble & 0x4)? LCD_D6 : 0;
  value |= (nibble & 0x8)? LCD_D7 : 0;
  value |= BACKLIGHT_ON | LCD_EN | (WRITE << RW) | (mode << RS); //Backlight, enable (high), read/write and command/data
  return value;
}

bool sendDataSingleByte(byte data, byte mode) {
  //Reuse function sendData() but for just one single byte
  return sendData(&data, 1, mode);
}

bool sendData(const byte* data, uint8_t data_length, byte mode) {
  //Send one or more bytes to LCD with I2C, split into two nibbles (4 bit length mode)
  //mode is COMMAND or DATA, data_length is the length of the data array
  //Call this function like this: sendData({0x64, 0x65, 0x66}, 3, DATA)
  if (!I2CStart(WRITE)) { //Send start condition followed by address and read/write bit (multiple tries in I2CStart())
      return false; //Error
  }
  byte EN_LOW = ~LCD_EN; //And byte with this to toggle EN (enable) LOW
  for (uint8_t i = 0; i < data_length; i++) { //Send each byte
    for (int n = 1; n >= 0; n--) { //Same procedure for first high then low nibble
      byte nibble = (data[i] >> (4 * n)) & 0x0f; //This is first high nibble of data[i] and then low nibble
      byte value = buildByte(nibble, mode);
      if (!sendByte(value)) return false; //Send one nibble (first high then low)
      delayMicroseconds(2);
      if (!sendByte(value & EN_LOW)) return false; //Pulse EN from HIGH to LOW
      delayMicroseconds(50);
    }
  }
  I2CStop(); //Send stop condition (it is ok(?) to not ignore last ACK-bit)
  return true;
}
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

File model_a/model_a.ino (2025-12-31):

//
//    ┏━━━━━━━━━━━━━━━━━━━┱─────────┐
//    ┃ DEC-HEX Converter ┃ model A │
//    ┗━━━━━━━━━━━━━━━━━━━┹─────────┘
//             Oskar Fornander, 2025
//


//    DEC-HEX Converter, Oskar Fornander, July-October 2025
//    ATtiny85/45, seven segment displays or LCD and a rotary encoder, driven by 3xAA/AAA-batteries.
//    Power consumption on average is about 70mA (~21 segments on). With AAA-batteries at 1000mAh it can be on for about 14 hours.
//      Model A: Shift registers (74HC595) and seven segment displays, with power button.
//      Model B: LCD-display with I2C-module. No power button.
//    This device will simultaneously count in decimal (0-255) and hexadecimal (00-FF) and in that way work as a converter between the two bases.
//    The code is optimized for speed, efficient use of memory and low power consumption on the ATtiny85 or ATtiny45, running at 8MHz.
//    
//    This file contains code for model A
//      The device clears the display and enters sleep mode automatically after some time of inactivity to save battery. Can be woken by turning the rotary encoder or reset by pressing (or turned off with power button).
//      Note: even in sleep mode the device draws just under 1mA (compared to about 70mA when running), so the batteries would last as most up to about 45 days. It is the shift registers (74HC595) that each draws around 80uA in this mode, and there is no easy way around this.
//      In the power saving mode the displays are flashing once every minute (64s) to let the user know it is still turned on.



/*
Connections to the ATtiny85:

pin  Arduino pin type            connection
----|-----------|---------------|--------------
1    PB5/RESET                   Push button   | (Push button with external pull up resistor)
2    PB3         INPUT           B             | Rotary encoder, low pass filter and external pull up resistor for both A and B. 
3    PB4         OUTPUT          Clock (SRCLK) | Shift register 74HC595
4    -                           GND
5    PB0         OUTPUT          Data (SER)    |
6    PB1         OUTPUT          Latch (RCLK)  |
7    PB2         INPUT           A             | (This pin can have interrupt)
8    -                           VCC

Reset button will reset the ATtiny85, so the start up sequence must be short and reset the counter and display 0 at the displays.


Displays:
Decimal: 3 x seven segment displays
Hexadecimal: 2 x seven segment displays

All is controlled with negative logic, values for each digit stored in memory, and bits inverted when sent.
Bits are sent to shift register in MSB first order: Hex, Dec. 

5 Shift registers (74HC595) are used in series. Three pins control Data (connected in series), Clock and Latch (common for all registers).
Output enable (OE) for all shift registers are connected to an RC-circuit with a transistor to delay showing data on the displays at startup, allowing the reset sequence to finnish first.
The outputs of the shift registers A-G are connected, in order, to seven segment digits G-A, H and DP are not connected.

*/

#include <avr/pgmspace.h>

#include <avr/sleep.h>
#include <avr/power.h>
#include <avr/wdt.h>
//#include <EEPROM.h>

//Define pins
#define PIN_ROTARY_ENCODER_A PB2
#define PIN_ROTARY_ENCODER_B PB3

#define PIN_DISPLAY_DATA PB0
#define PIN_DISPLAY_LATCH PB1
#define PIN_DISPLAY_CLOCK PB4

//Define constants and variables for sleep
#define WAIT_FOR_SLEEP 60000 //1 * 60 * 1000 ms, i.e. 1 minutes
#define WAKE_UP_DELAY 1000 //1 second
#define WDT_CYCLES 1 //Blink display after this many sleep cycles: 1*8=8s (Watchdog timer interval for sleep: 8s)
unsigned long lastTimeActive = 0; //Stores the time millis() after the last activity, to check for millis() - lastTimeActive > WAIT_FOR_SLEEP
unsigned long wakeUpTime = -WAKE_UP_DELAY; //millis() when woken up. Used to ignore rotation of the rotary encoder for a moment after wake up. Set to negative value to ignore this at startup and reset.
volatile uint8_t sleepCycles = 0; //Count the number of sleep cycles (at most WDT_CYCLES as defined above)
volatile bool externalWakeup = false; //Device is woken by external interrupt 


byte counter = 0; //global counter variable in interval [0, 255], this is the value to be displayed in decimal and hexadecimal

//Bit fields to store the flags that keep track of the rotary encoder status
struct {
  uint8_t currentA : 1; //Previous and current readings of the rotary encoder pins A and B. 1 for true and 0 for false. Using single bit sto store information for each.
  uint8_t prevA : 1;
  uint8_t currentB : 1;
  uint8_t prevB : 1;
  uint8_t transition : 4; //Transitions from one state to another (4 bits: A'B'AB)
  int8_t counter : 4; //Counting states of the rotary encoder. 4 bits to store values from -4 to 4 (-8 to 7)
  uint8_t valueChanged : 1; //Flag to indicate that the value of counter has changed (using one bit instead of one byte with a comparison number to save space)
} rotaryStates;

byte sevenSegmentDigit[16] = { //Values for each digit, 1 for segment on and 0 for segment off. Decimal point is not used. Segments in this order: .abcdefgh (decimal point is MSB, h is LSB) Byte is sent MSB fist.
  0b01111110,  //0
  0b00110000,  //1
  0b01101101,  //2
  0b01111001,  //3
  0b00110011,  //4
  0b01011011,  //5
  0b01011111,  //6
  0b01110000,  //7
  0b01111111,  //8
  0b01110011,  //9
  0b01110111,  //A
  0b00011111,  //B
  0b01001110,  //C
  0b00111101,  //D
  0b01001111,  //E
  0b01000111}; //F
byte sevenSegmentBlank = 0b00000000; //Blank display
byte sevenSegmentFull = 0b11111111; //Full display
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

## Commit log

2025-11-22 Add PCB images
2025-11-23 Update Assembly instructions and parts list
2025-11-24 Update parts list and assembly instructions
2025-11-24 Update assembly instructions
2025-11-28 Update assembly instruction
2025-11-30 Add files for 3d printing
    [DEC-HEX Converter model A box.3mf, DEC-HEX Converter model A box.stl, DEC-HEX Converter model B box.3mf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]
2025-12-31 Update error with pull up resistors.
    [model_a.ino, model_b.ino]
2025-12-31 Update schematic
2026-05-15 Update schematics
2026-05-26 Update info for new pcb revision sponsored by PCBWay
2026-05-27 Add image of new PCB
2026-05-27 Update comment about new pcb
